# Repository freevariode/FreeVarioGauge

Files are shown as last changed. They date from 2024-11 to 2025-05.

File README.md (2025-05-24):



# FreeVario.de
</br>

### New in V2.4.2:

- files from the data folder can be uploaded OTA via the web interface
 </br>
 
### New in V2.4.1:

- Bug fix for wind display when FreeVario is only connected to Larus
 </br>
 
### New in V2.4:

- Optimization of the menu for direct connection to the Larus without OpenVario
 </br>
 
### New in V2.3:

- Improvement of device detection (XCSoar or Larus)

- improved connection to Larus

- optimized data transfer using the BT-RS232 bridge from FreeVario
 </br>
 
### New in V2.2:

- Improved wind arrow color

- STF bug fix

- in the menu, instead of using the slide switch on the board, set whether XCSoar or flap switch should switch between STF and Vario in automatic mode

- Improvements to variosound

- Improvement when setting McCready
 </br>

### New in V2.1:

- improving sound if entering update mode

- prepare VarioSound for hardware version 2.0
 </br>
 
### New in V2.0:

- Wind direction and strength of the external wind (Larus, Anemoi, etc.) is displayed

- if this is not available, the wind calculated by XCSoar is displayed

- Function can be deactivated in the menu

- the FreeVario can now also be used as a standalone device for Larus. It can be connected directly to the Larus without XCSoar 

- A FreeVario image with OpenSoar is required for OpenVario larger than 24096

- The official OpenSoar image does not yet support the feature. But that will come soon.

- With a FreeVario version lower than 1.2.2, the data folders for the sound board and the graphics board must also be re-uploaded!
 </br>
 
### New in V1.3:
 
- Bugfix: Mosquito value was not displayed correctly
</br>

### New in V 1.2.3:

- In STF mode, net Vario is now shown at the top of the display, and in Vario mode the average climb is shown. The image for the OpenVario must be larger than 23313!
</br>

### New in V 1.2.2:

- Revision of the web interface for updates

- IMPORTANT!! After the update to V 1.2.2, the two data folders must be reloaded into the memory of the display and soundboard
</br>

### New in V 1.2.1:

- the update of the two ESPs can now be carried out even more easily via the WiFi (OTA)

- IMPORTANT!! After updating to V 1.2.1, the folder data must be reloaded into the display board’s memory

- See the assembly instructions, Chapter III, variant 1, from point 17
</br>

### New in V1.2:

- Both ESPs could be updated using WiFi (OTA)
</br>

### New in V1.1.5 (OpenVario image from FreeVario.de at least 22193 required):

- Attenuation (ATT) adjustable in the menu between 0 and 3

- Altitude and speed settings, as well as damping rate and mute settings are stored in the device

- After the OpenVario crashes, the devices synchronize again

##
</br>

### IMPORTANT - PTT and mute function

If you want to use the FreeVario's mute function, you need to have at least the FreeVario image from 20295 installed on your OpenVario. In addition, at least firmware V.1.1.1 must be installed on the sound board as well as on the display board. If you are using the sound board with the 3-pin connector on the back, but without the diode D1, a small change has to be made here. Please write me about this by email (dirk@freevario.de).

The FreeVario is an open source e-variometer that works together with the XCSoar software. It shows the mean climb (30s), 
the height above sea level (MSL) or the height above ground (AGL), the ground speed (GS) or tue airspeed (TAS), the MC, 
QNH or bug value. MC, QNH, or bug value can be set via the menu and the rotary encoder, and are then passed on 
to XCSoar. In addition, a colored bar, which represents the climb value that can be grasped quickly, shows the current climb. 
The bar shows climbing green and falling red. The acoustic display of the climbing value is as known by other e-Varios and 
no longer has to be generated by the OpenVario. The OpenVario can therefore issue airspace warnings again. The volume can be 
adjusted using the lower rotary knob. The toggle switch can be used to switch between speed to fly and vario. In the middle 
position, XCSoar or a switch attached to the flaps automatically decides whether spped to fly or vario should be active.

On the back are an RJ45 and a small 2-pin socket. The e-Vario is connected to the OpenVario via the RJ45 socket. The small 
2-pin socket can be connected to a switch on the flaps.

The e-Vario fits into a 57mm standard cutout. The housing has the dimensions: 65x65x90 (LxWxD) and is printed with a 3D 
printer made of PLA or PETG

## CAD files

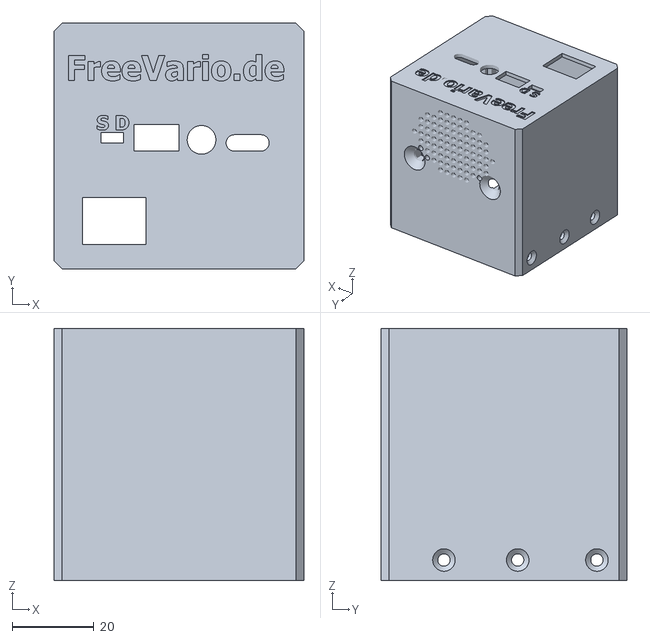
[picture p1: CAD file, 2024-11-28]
Housing/body_housing.stl
61.0 x 60.0 x 61.5

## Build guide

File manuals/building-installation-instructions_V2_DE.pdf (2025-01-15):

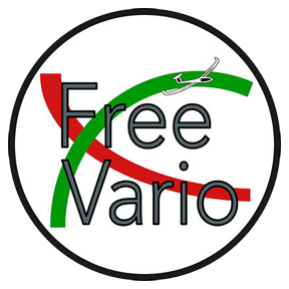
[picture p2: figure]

Copyright Dirk Jung | licensed under CC BY-SA | Page 1

## Bau- und Installationsanleitung für das FreeVario V2

## Inhaltsverzeichnis

V. Installieren des neuen OV-Images inkl. XCSoar mit FreeVario-Treiber.........13

VI. Installieren von XCSoar inkl. FreeVario-Treiber ohne Neuinstallation des OV-

XIV. Aktualisieren von Karten, Lufträumen etc. mit dem neuen Menü von

Rev. 2.2 (01.2025)

Ich arbeite auf einem Mac bzw. Linuxsystem. Auf einem Windowsrechner können Kleinigkeiten abweichen!

I. Allgemeines

Das FreeVario wird mit 12V betrieben, kann aber auch alternativ mit 5V betrieben werden.
Die Maßgenauigkeit der 3D-gedruckten Teile hängt extrem von den Einstellungen eures Druckers und vom Material ab. Es kann also vorkommen, dass die Teile zu klein sind. Dann müsst ihr die Teile um wenige Prozent größer drucken.

II. Bestücken der Platinen und Zusammenbau des e-Varios

1. PCB1 sowie auf den Bildern dargestellt zusammenlöten.

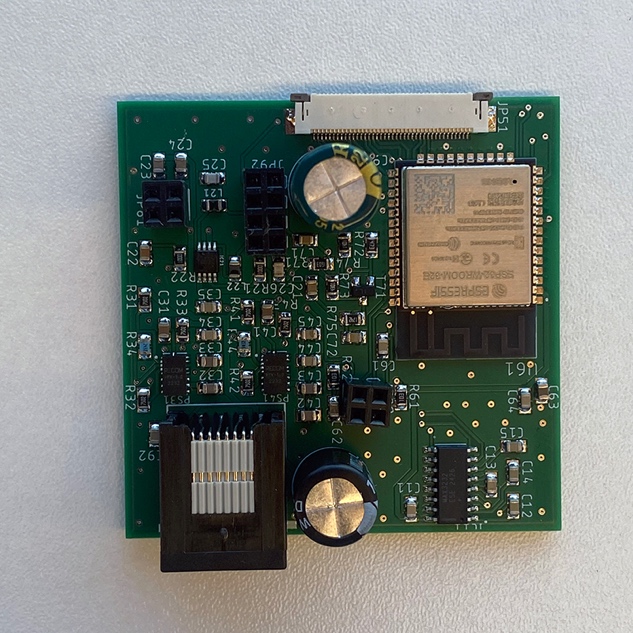
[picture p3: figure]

2. PCB2 sowie auf den Bildern dargestellt zusammenlöten. Der Abstand der beiden Kunststoffhalterungen der Stapelleiste muss auf 8mm eingestellt werden. Die zu langen Stifte mit einem Seitenschneider auf 22 mm kürzen (siehe 3. Bild).

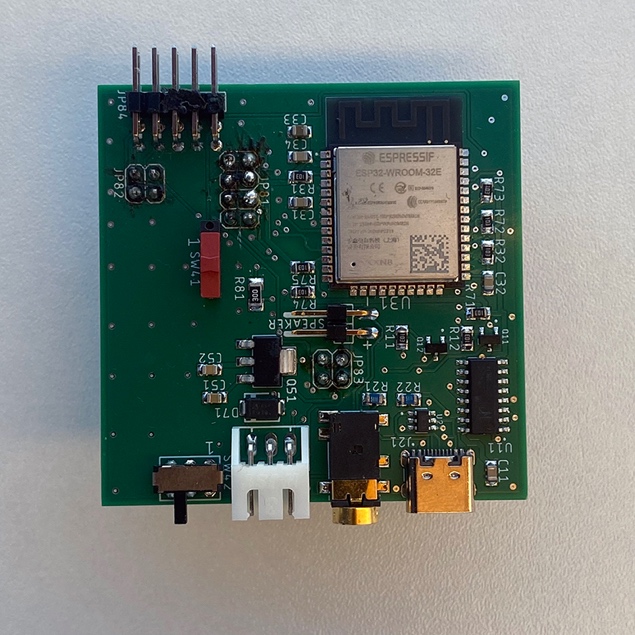
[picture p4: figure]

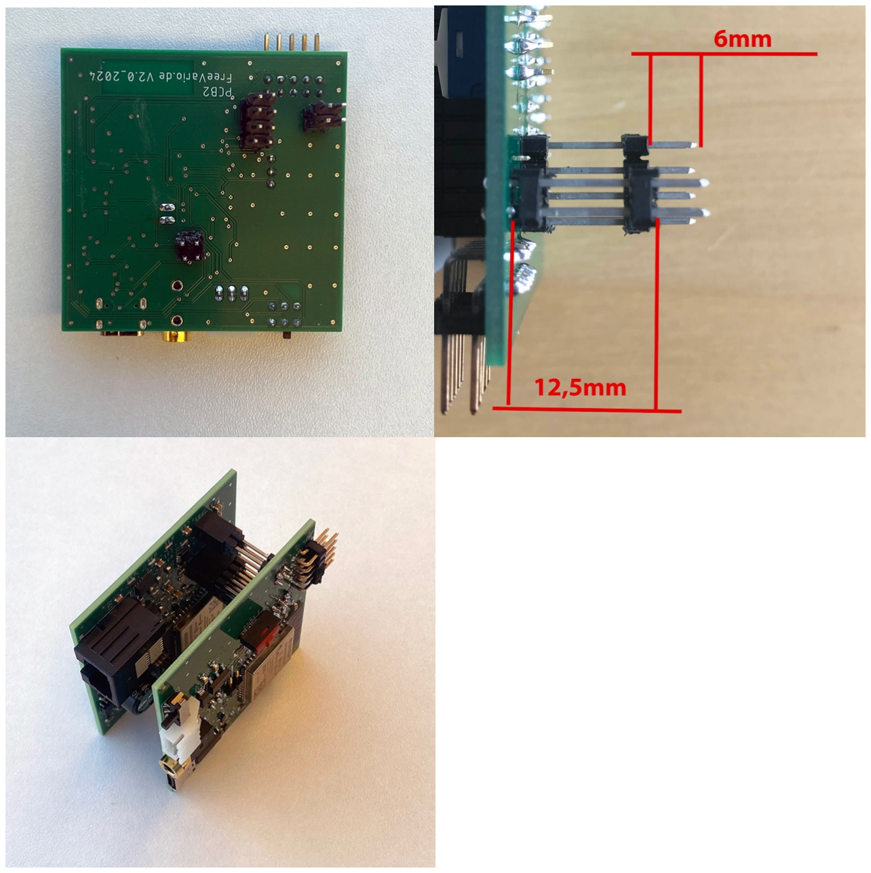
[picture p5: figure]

Die 3,5mm Klinkenbuchse dient zum Anschließen eines externen Lautsprechers. Wird der externe Lautsprecher angeschlossen, wird der interne automatisch abgeschaltet.

3. Den Drehencoder vorsichtig zerlegen, indem ihr die kleinen Metallbügel aufbiegt. Die Achse des Drehencoders ist mit einem Sicherungsring gesichert. Ihr müsst mit einem Seitenschneider vorsichtig in den Spalt zw. Achse und Gehäuseoberteil gehen und leicht drücken. Wenn die Achse durch den Seitenschneider leicht beschädigt wird, die Stelle wegfeilen. Die Achsen in die Drehmaschine einspannen auf 4mm abdrehen. Anschließend den Drehencoder wieder sorgfältig zusammensetzen und die Metallbügel zurück biegen. Die Achse des Drehencoders wieder mit dem Ring sichern. Kauft euch den Drehencoder sicherheitshalber doppelt, beim ersten Mal geht es ggf. schief. Bohrt die Hohlschrauben auf 4,3mm auf.
4. Am PCB3 an der Position, wo der Encoder sitzt, müsst ihr auf der Seite mit den 3 PINs und oben noch den überstehenden Teil der Platine wegfeilen, sonst passt die Platine nicht spannungsfrei in das Gehäuse. Es kann durchaus sein, dass ihr hier nach dem Löten noch mal ein wenig feilen müsst. Die Kontakte des Potentiometers vorsichtig um 90° nach unten biegen und anlöten. Testet, ob nach der Montage der Frontplatte die Achsen des Encoders und des Potentiometers gut durch die Hohlschrauben passen und sich leicht betätigen lassen. Gegebenenfalls noch mal lösen und etwas verschieben.

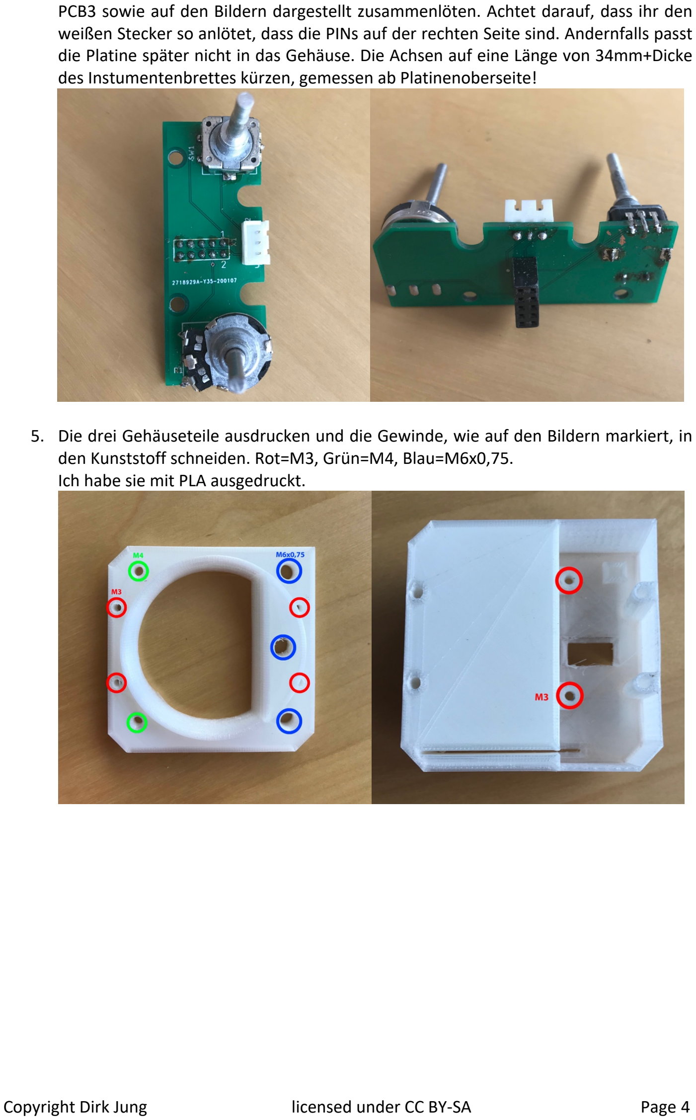
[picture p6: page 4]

PCB3 sowie auf den Bildern dargestellt zusammenlöten. Achtet darauf, dass ihr den weißen Stecker so anlötet, dass die PINs auf der rechten Seite sind. Andernfalls passt die Platine später nicht in das Gehäuse. Die Achsen auf eine Länge von 34mm+Dicke des Instumentenbrettes kürzen, gemessen ab Platinenoberseite!

5. Die drei Gehäuseteile ausdrucken und die Gewinde, wie auf den Bildern markiert, in den Kunststoff schneiden. Rot=M3, Grün=M4, Blau=M6x0,75.
Ich habe sie mit PLA ausgedruckt.

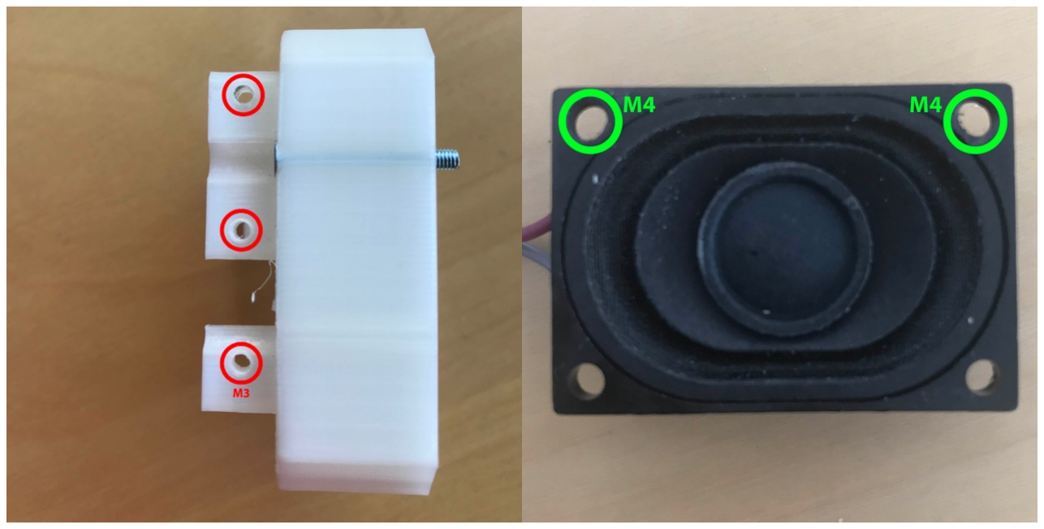
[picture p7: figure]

6. Zwei Gewinde M4 in den Lautsprecher schneiden und Lautsprecher mit 2 Senkkopfschrauben M4x8 im Gehäuse befestigen. Vorher etwa 10cm lange Kabel zum Anschließen des Lautsprechers anlöten. Der Lautsprecher ist nur erforderlich, wenn das FreeVario den Varioton ausgeben soll. Wollt Ihr weiterhin den Varioton von OpenVario nutzen, könnt ihr den Lautsprecher weglassen.
7. Stecker an ein etwa 5cm langes, 3-poliges Kabel krimpen und an den Kippschalter anlöten. Lötet so platzsparend wie möglich, in dem ihr schräg anlötet. Andernfalls gibt es später zwischen den Lötstellen und den dahinterliegenden Kontakten auf dem PCB3 einen Kurzschluss. Macht unbedingt Schrumpfschlauer die Lötkontakte!
Das mittlere Kabel kommt an die mittlere Lötfahne. Je nachdem wie ihr die beiden äußeren Kabel anlötet, habt ihr später STF oder Vario oben. Wenn ihr das obere Kabel des Steckers an die obere Lötfahne des Kippschalters, und das untere Kabel des Steckers an die untere Lötfahne des Kippschalters lötet, ist später Sollfahrt in der unteren Position des Kippschalters, und Vario in der oberen. Automatik ist in der Mitte.
8. Die Gewinde der beiden M4 Befestigungsschrauben auf 3mm + Instumentenbrettdicke kürzen. Arbeitet hier sehr genau, denn wenn die Schrauben zu lang sind, drücken Sie später auf das Display und zerstören es. Am besten ihr schraubt die Frontblende alleine einmal in das Cockpit und checkt, dass die Schrauben nicht in den Bereich des Displays ragen.
9. Kippschalter und das Display in die Frontblende einbauen.
10. PCB3 in das Mittelteil einsetzen und mit 2 Schrauben M3x6 festschrauben. Schrauben mit Gefühl anziehen, die Gewinde sind im Kunststoff!
11. Frontblende und Mittelteil mit 4 Senkkopfschrauben M3x25 zusammenschrauben. Vorher den Kippschalter anklemmen und das FFC-Kabel durch den Schlitz nach hinten führen. Schrauben mit Gefühl anziehen, die Gewinde sind im Kunststoff!

12. Testet nun zu erst, ob sich die beiden Platinen einzeln leicht in den Topf schieben lassen. Andernfalls kann es später zu Beschädigungen kommen. Im Zweifel die Nut etwas nacharbeiten.
13. PCB1 und PCB2 vorsichtig zusammensetzen, Display, Lautsprecher (Plus und Minus nicht vertauschen) und PBC3 anschließen. Den Klemmmechanismus des Displaykabels sehr vorsichtig mit einem kleinen Schraubenzieher oder ähnlichem schließen. Wenn ihr mit den Fingern oder dem falschen Werkzeug abrutscht, kann es leicht passieren, dass euch das Flachbandkabel einreißt.
14. Nun springt ihr am besten zuerst zum Programmieren der beiden ESP32, und macht anschließend hier weiter.
15. Nun den Gehäusetopf vorsichtig über die Platinen schieben. Darauf achten, dass die Platinen in den Schienen sind, und die Western-Digital-Buchse vorsichtig durch die Rückwand führen.
16. Mit 6 Senkkopfschrauben M3x6 die Gehäuseteile verschrauben. Schrauben mit Gefühl anziehen, die Gewinde sind im Kunststoff!
17. Mit den beiden Befestigungsschrauben und den beiden Hohlschrauben das Vario im I-Brett einbauen, die Drehknöpfe montieren und das Vario anschließen. Schrauben mit Gefühl anziehen, die Gewinde sind im Kunststoff!
18. Das Anschlusskabel ist auf beiden Seiten gleich belegt, d.h. gleiche Farbe auf gleichem PIN, so wie ein normales LAN-Kabel.

III. Programmieren und Updaten der beiden ESP32
Mit dem kleinen Schiebeschalter auf der Rückseite des FreeVarios könnt ihr auswählen, welchen der beiden ESP’s ihr beschreiben wollt (D=Display-ESP, S=Sound-ESP).

Variante 1: die Software-Version des FreeVarios ist kleiner als 1.2 oder die ESPs sind noch nicht programmiert worden:
1. Legt euch den Ordner Binaries z.B. auf den Desktop
2. Ladet euch ALLE Binaries von der Webseite herunter und speichert sie in diesem Ordner
3. Öffnet ein Terminal oder die Eingabeaufforderung. Dort schaut ihr, ob ihr den Pfad zu Binaries findet. Er lautet bspw. /Users/PC1/Desktop/Binaries/
4. In Arduino IDE auf Arduino -> Einstellungen klicken.
5. Unter „Zusätzliche Boardverwalter-URLs“ die URL hinzufügen. Sind schon URLs eingetragen, mit Komma und Leerzeichen weitere URLs anhängen. https://dl.espressif.com/dl/package_esp32_index.json

6. Hier außerdem unter „Ausführliche Ausgabe während“ „Hochladen“ anklicken.
7. Werkzeuge -> Board -> Boardverwalter klicken und nach ESP32 suchen.
8. „ESP32 by Espressif Systems“ auswählen und installieren.
9. Ihr müsst euch ggf. noch den Treiber für den seriellen Adapter des ESP installieren. https://sparks.gogo.co.nz/ch340.html
10. Einen neuen Sketch öffnen und speichern. Merkt euch den Namen. Zum Hochladen folgendes unter Werkzeuge einstellen:
- Board: DOIT ESP32 DEVKIT V1
- Upload Speed: 115200
- Flash Frequency: 80MHz
- Core Debug Level: “Keine”
- Port: Schaue, welche nach dem Anschließen des ESP32 mit dem USB-Kabel neu dazu kommt
11. Dann den leeren Sketch hochladen. Über der Fehlermeldung im Arduino IDE steht in weißer Schrift ein sehr langer Befehl, der in etwa wie folgt lautet: /Users/PC1/Documents/Arduino/hardware/espressif/esp32/tools/esptool/esptool --chip esp32 --port /dev/cu.SLAB_USBtoUART --baud 115200 --before default_reset --after hard_reset write_flash -z --flash_mode dio --flash_freq 80m --flash_size detect 0xe000
/Users/PC1/Documents/Arduino/hardware/espressif/esp32/tools/partitions/boot_ap p0.bin 0x1000
/Users/PC1/Documents/Arduino/hardware/espressif/esp32/tools/sdk/bin/bootloader _dio_80m.bin 0x10000
/var/folders/6t/qjgfw2413f7ddnjzk_08btxw0000gp/T/arduino_build_661147/sketch_ dec30d.ino.bin 0x8000
/var/folders/6t/qjgfw2413f7ddnjzk_08btxw0000gp/T/arduino_build_661147/sketch_ dec30d.ino.partitions.bin
12. Diesen Befehl kopieren, den braucht ihr um die Datei auf den ESP32 zu laden.
13. Der erste Teil des Befehls zeigt euch, wo Arduino IDE sein Arbeitsverzeichnis anlegt. Merkt euch den Ort. In diesem Beispiel wäre das: /Users/PC1/Documents/Arduino
14. Ändert den Befehl mit eurem Ort, an dem der Ordner Binaries liegt, ab. Ändert außerdem die beiden letzten Dateinamen wie folgt ab (siehe Fettdruck).

Display-ESP:
/Users/PC1/Documents/Arduino/hardware/espressif/esp32/tools/esptool/esptool --chip esp32 --port /dev/cu.SLAB_USBtoUART --baud 115200 --before default_reset --after hard_reset write_flash -z --flash_mode dio --flash_freq 80m --flash_size detect 0xe000 /Users/PC1/Desktop/Binaries/boot_app0.bin 0x1000 /Users/PC1/Desktop/Binaries/FreeVarioGauge.ino.bootloader.bin 0x10000

/Users/PC1/Desktop/Binaries/FreeVarioGauge.ino.bin 0x8000 /Users/PC1/Desktop/Binaries/FreeVarioGauge.ino.partitions.bin
Sound-ESP:
/Users/PC1/Documents/Arduino/hardware/espressif/esp32/tools/esptool/esptool --chip esp32 --port /dev/cu.SLAB_USBtoUART --baud 115200 --before default_reset --after hard_reset write_flash -z --flash_mode dio --flash_freq 80m --flash_size detect 0xe000 /Users/PC1/Desktop/Binaries/boot_app0.bin 0x1000 /Users/PC1/Desktop/Binaries/VarioSound.ino.bootloader.bin 0x10000 /Users/PC1/Desktop/Binaries/VarioSound.ino.bin 0x8000 /Users/PC1/Desktop/Binaries/VarioSound.ino.partitions.bin
15. Den ESP32 mit dem USB-Kabel am PC anschließen und ein Terminal bzw. die Eingabeaufforderung öffnen. Dort den jeweils passenden Befehl absetzen.
16. Nachdem der Upload abgeschlossen ist, startet der ESP32 neu. Anschießend müssen noch die Dateien in den Speicher des jeweiligen ESP32 hochgeladen werden.
17. Das Programm ESP32 Sketch Data Upload funktioniert aktuell nur bis Ardoino IDE 1.8.19!
18. ESP32 | Sketch | Data | Upload | installieren. | Dazu | ESP32FS-1.1.zip | bei
https://github.com/me-no-dev/arduino-esp32fs-plugin/releases/ herunterladen.
19. Auf dem Mac den entpackten Ordner ESP32FS nach /Dokumente/Arduino/tools kopieren.
20. Unter Windows den entpackten Ordner ESP32FS nach /Programme/Arduino/tools kopieren.
21. Die Dateien sound_data.zip und display_data.zip von der Webseite herunterladen und entpacken. Geht in das Arbeitsverzeichnis von Arduino IDE (z.B. /Users/PC1/Documents/Arduino) und dort in den Ordner eures eben angelegten Sketches. Hierher den entpackten Ordner data für den Sound-ESP oder den Display ESP kopieren, je nach dem auf welchen ihr gerade hochladen wollt.
22. Arduino IDE neu starten, euren neu angelegten Sketch öffnen.
23. WICHTIG!! Darauf achten, dass der serielle Monitor geschlossen ist.
24. Nun unter Werkzeuge „ESP32 Sketch Data Upload“ anklicken.
25. Nach dem der Upload abgeschlossen ist, startet der ESP32 neu und, falls das Display schon angeschlossen ist, seht ihr nun auch die Anzeige des e-Varios.
26. Nun geht zurück zu Punkt 13 des Montageteils der Anleitung.

Variante 2: die Software-Version des FreeVarios ist 1.2:

Anmelden der ESPs in einem WLAN
1. Schaltet das FreeVario ein und lasst, wenn möglich, das OpenVario aus. Sollte es nicht möglich sein, die Geräte unabhängig voneinander einzuschalten, beendet über das Menü im OpenVario XCSoar. Während des Updates sollte XCSoar nicht versuchen mit dem FreeVario zu kommunizieren.
2. Solange das Display die Versionsnummer zeigt, könnt ihr in den Update-Modus wechseln.
3. Legt dazu den Kippschalter von der obersten in die unterste, oder von der untersten in die oberste Position.
4. Das Soundboard quittiert den Update-Modus mit einem Peepston, das Displayboard zeigt auf dem Bildschirm „starting Update Mode“ an.
5. Finden die beiden ESPs kein WLAN, mit dem sie sich verbinden können, starten Sie im Access Point Mode, das bedeutet, sie stellen selbst ein WLAN zur Verfügung.
6. Da eine Weile versucht wird, sich in ein WLAN einzuwählen, kann dieser Prozess etwa 1 Minute dauern.
7. In welchem Modus sich welcher ESP befindet, und über welche IP er erreichbar ist, wird auf dem Bildschirm angezeigt.
8. Der Access Point des Soundboards heißt „FreeVario_Soundboard“, der Access Point des Displayboard heißt „FreeVario_Displayboard”
9. Verbindet euch mit eurem Rechner oder Handy mit einem der beiden Access Points und ruft im Browser die jeweils angezeigte IP auf.
10. Dort findet ihr eine Liste der gefundenen WLAN-Netzwerke. Sucht euch das aus, mit dem sich der ESP verbinden soll, und gebt die passende SSID und das WLAN-Passwort ein.
11. Nun werden die Verbindungsdaten im EEPROM gespeichert. Dort können nur die Verbindungsdaten für ein WLAN gespeichert werden. Wenn ihr euch mit einem anderen verbindet, werden die alten Verbindungsdaten gelöscht.
12. Startet das FreeVario neu, geht wieder in den Update-Mode und wiederholt die Schritte 9 – 11 mit dem anderen Access Point.
13. Die Schritte 1 – 12 müsst ihr zukünftig nicht wiederholen, wenn ihr im gleichen WLAN bleibt.

ESPs verbinden sich bereits mit einem WLAN
14. Ladet euch von FreeVario.de die Binarie-Dateien VarioSound.ino.bin und FreeVarioGauge.ino.bin herunter und speichert sie auf eurem Gerät.
15. Startet das FreeVario wieder neu und geht wieder in den Update-Mode.
16. Nun verbinden sich beide ESPs mit dem ausgewählten WLAN. Verbindet euren Rechner oder euer Handy ebenfalls mit diesem WLAN und ruft im Browser einer der beiden im Display angezeigten IPs auf.
17. Tragt beim Soundboard jeweils für Passwort und Login „Sound“ ein.
18. Tragt beim Displayboard jeweils für Passwort und Login „Display“ ein.
19. Wählt beim Soundboard die Datei VarioSound.ino.bin, und beim Displayboard die Datei FreeVarioGauge.ino.bin aus und klickt auf Update.
20. Das Update dauert ca. 1 Minute und die erfolgreiche Beendigung wird beim Displayboard durch einen Neustart des Displays angezeigt. Beim Soundboard erhält man leider keine Rückmeldung.
21. Startet das FreeVario neu, geht wieder in den Update-Mode und wiederholt die Schritte 16 – 20 für den anderen ESP.
22. Nach einem erneuten Neustart des FreeVarios ist der Vorgang abgeschlossen.

Variante 3: die Software-Version des FreeVarios ist mindestens 1.2.1:
1. Ladet euch von FreeVario.de die Binarie-Dateien VarioSound.ino.bin und FreeVarioGauge.ino.bin herunter und speichert sie auf eurem Gerät.
2. Schaltet das FreeVario ein und lasst, wenn möglich, das OpenVario aus. Sollte es nicht möglich sein, die Geräte unabhängig voneinander einzuschalten, beendet über das Menü im OpenVario XCSoar. Während des Updates sollte XCSoar nicht versuchen mit dem FreeVario zu kommunizieren.
3. Solange das Display die Versionsnummer zeigt, könnt ihr in den Update-Modus wechseln.
4. Legt dazu den Kippschalter von der obersten in die unterste, oder von der untersten in die oberste Position.
5. Das Soundboard quittiert den Update-Modus mit einem Peepston, das Displayboard zeigt auf dem Bildschirm „starting Update Mode“ an.
6. Nun stellt das Displayboard das WLAN FV_Displayboard, und das Soundboard das WLAN FV_Soundboard zur Verfügung. Das Passwort ist jeweils 12345678.
7. Das WLAN des ESP32 erzeugt Störgeräusche im Audioverstärker, das ist leider normal.

8. Wenn ihr euch mit einem der beiden WLAN’s verbunden habt, könnt ihr die Updateseite des jeweiligen Boards in eurem Browser aufrufen.
9. Gebt dazu als URL FreeVario_Displayboard.local bzw. FreeVario_Soundboard.local, oder alternativ die auf dem Display angezeigte IP ein.
10. Wählt beim Soundboard die Datei VarioSound.ino.bin, und beim Displayboard die Datei FreeVarioGauge.ino.bin aus und klickt auf Update.
11. Das Update dauert ca. 1 Minute und die erfolgreiche Beendigung wird beim Displayboard durch einen Neustart des Displays angezeigt. Beim Soundboard erhält man leider keine Rückmeldung.
12. Startet das FreeVario neu, geht wieder in den Update-Mode und wiederholt die Schritte 16 – 20 für den anderen ESP.
13. Nach einem erneuten Neustart des FreeVarios ist der Vorgang abgeschlossen.

IV. Sichern und wiederherstellen eurer Einstellungen

1. Sichern der Einstellungen:

Variante 1: das originale Menü wird verwendet:
- Sichern des Ordners .xcsoar vom alten System
- OpenVario booten und ins Menü gehen. Dort „Exit to the shell“ auswählen und mit Yes bestätigen. Euren USB-Stick zum Verwalten des OpenVarios und eine USB-Tastatur anschließen. Gebt folgende Befehle ein.
- mkdir /tmp/USB
- mount /dev/„USB-Stick“ /tmp/USB (/„USB-Stick“ ist i.d.R. /dev/sda1)
- cp -r .xcsoar /tmp/USB (dauert etwas!)
- cd /tmp/USB
- mv .xcsoar xcsoar
- rm -r openvario/upload/xcsoar
- mv xcsoar openvario/upload/
- Sichern des Wertes zur Kalibrierung der Spannungsanzeige (falls ihr das überhaupt kalibriert habt, ansonsten Schritt überspringen):
- OpenVario booten und ins Menü gehen. Dort „Exit to the shell“ auswählen und mit Yes bestätigen. Schließt eine USB-Tastatur an und gebt folgende Befehle ein.
- nano /opt/conf/sensord.conf
- den Wert bei der Variablen „voltage_config” aufschreiben. Bei mir war das „voltage_config 1592.4 4.54545“.
- 1592.4 ist der Skalierungsfaktor, 4.54545 ist der Offset. Die Formel, um den Wert des AD-Wandlers in die Spannung umzurechnen, lautet:
U = (Wert AD-Wandler / Skalierungsfaktor) + Offset

- Sichern der WiFi-Einstellungen:
- Kopiert euch den Ordner /var/lib/connman auf den USB-Stick, der ja bereits gemountet ist.
- cp -r /var/lib/connman /tmp/USB

Variante 2: das neue Menü von Kedder wird verwendet:
- Steckt einen leeren FAT32 formatierten USB-Stick in das OpenVario
- Startet das OpenVario und wählt im Menü „Applications“ -> „Backup“ -> „Backup“ aus
- Alles wichtige wird nun automatisch gesichert
2. Hochladen eurer gesicherten Daten auf das OpenVario:

Variante 1: das originale Menü wird verwendet:
- Die neue SD-Karte in das OpenVario einsetzen, und starten. Dann wieder in das Menü von OpenVario gehen.
- „Copy file to and from OpenVario” -> „Upload files from USB to XCSoar” anklicken. Damit werden alle eure Einstellungen wiederhergestellt. Warten bis „Done!!“ Angezeigt wird.
- Anschließend unter „Update, Settings, …” -> „System Settings” mit „Set rotation of the display” die gewünschte Ausrichtung des Displays einstellen.
- Ggf. unter „Update, Settings, …” „Calibrate Touch” auswählen.
- unter „Update, Settings, …” „Calibrate Sensors” auswählen.
- Zuletzt noch unter „Update, Settings, …” -> „System Settings” -> „Set language used for XCSoar” die Sprache einstellen.
- Mit ESC zurück ins Hauptmenü und „Restart“ auswählen und mit Yes bestätigen.
- Kalibrierung der Spannungsanzeige wiederherstellen:
- nano /opt/conf/sensord.conf
- „voltage_config” wieder auf die notierten Werte setzen
- Sicherung alter WiFi-Einstellungen wiederherstellen:
- Den auf dem USB-Stick gesicherten Ordner connman wieder in das Verzeichnis /var/lib kopieren
- mkdir /tmp/USB
- mount /dev/„USB-Stick“ /tmp/USB (/„USB-Stick“ ist i.d.R. /dev/sda1)
- cp -r /tmp/USB/connman /var/lib
- WiFi wieder einrichten, wenn keine Sicherung der alten Einstellungen besteht:
- OpenVario booten und ins Menü gehen. Dort „Exit to the shell“ auswählen und mit Yes bestätigen. Schließt eine USB-Tastatur an und gebt folgende Befehle ein.
- connmanctl
- enable wifi
- scan wifi
- services
- agent on
- connect wifi_...
- Passwort eingeben

Variante 2: das neue Menü von Kedder wird verwendet:
- Steckt den USB-Stick mit eurer Sicherung in das OpenVario
- Startet das OpenVario und wählt im Menü „Applications“ -> „Backup“ -> „Restore“ aus
- Alles wichtige wird nun automatisch wieder hergestellt
V. Installieren des neuen OV-Images inkl. XCSoar mit FreeVario-Treiber
1. Ab dem offiziellen Image 21033 von OpenVario ist der FreeVario-Treiber im Image integriert. Ihr seid also nicht mehr darauf angewiesen, Images von FreeVario.de zu verwenden. Solltet ihr bereits ein Image ab 21033 installiert haben, könnt ihr das FreeVario direkt ohne Änderungen an eurer Software anschließen.
2. Installieren des neuen Images:

Variante 1: Neue SD-Karte verwenden (sichere Methode)
- Mit einem Linux-PC das neue Image auf eine andere SD-Karte schreiben. So könnt Ihr sicher sein, dass auf der alten Karte noch ein funktionierendes System ist, falls etwas schief geht.
- das Image zuerst entpacken:
- gunzip “Pfad_zum_Image“
- z.B.: gunzip /home/USER/Schreibtisch/OpenVario-linux-openvario-image-testing-glibc-ipk-20149-openvario-7-PQ070.rootfs.img.gz
- dd if=“Pfad_zum_Image“ of=/dev/„neue_SD-Karte“
- z.B.: dd if=OpenVario_neu.img of=/dev/sda

Variante 2: Alte SD-Karte überschreiben (unsichere Methode)
- In das Hauptverzeichnis des USB-Sticks „openvario“ legt ihr die recovery-Datei „ov-recovery.itb“, die ihr auf dem FTP-Server (ftp://ftp.openvario.org/recovery) herunterladen könnt.
- WICHTIG!! Wenn ihr keine Wiederherstellung durchführen wollt, muss die Datei „ov-recovery.itb“ unbedingt umbenannt werden, z.B. in „ov-recovery.xxx“.
- Kopiert das zu installierende Image als .gz-Datei auf den USB-Stick in den Unterordner images
- Steckt den USB-Stick in das OpenVario und bootet.
- Das Wiederherstellungsmenü wird in Rot dargestellt. Denkt daran, dass beim Ausführen der Wiederherstellung alle Dateien im OpenVario gelöscht werden!
- Wählt „Write image to SD Card“ und anschließend „Update complete SD Card“ aus

VI. Installieren von XCSoar inkl. FreeVario-Treiber ohne Neuinstallation des OV-Images

1. Wenn ihr nicht dass komplette Image von OV neu installieren wollt, sondern nur die Version von XCSoar austauschen wollt, dann könnt ihr das wie unten beschrieben tun. Dabei bleiben eure Einstellungen in XCSoar komplett erhalten. Eine Sicherungsdatei der SD-Karte würde ich mir aber immer vorher anlegen. Schief gehen kann immer mal was!
2. Die neue Version der Installationsdatei von XCSoar auf einen USB-Stick kopieren, im Menü von OpenVario „Exit to the shell“ auswählen. Dort mit fdisk -l den Pfad des USB-Stick finden (z.B. /dev/sda1).
3. mkdir /tmp/USB
4. mount /dev/sda1 /tmp/USB
5. cd /tmp/USB
6. opkg remove xcsoar
7. opkg install xcsoar*.ipk
8. Im Menü von OpenVario noch mal die Sprache neu einstellen, und einen Reboot machen.

VII. Abschalten des Variotons vom OpenVario

### 1. Überspringt diesen Abschnitt komplett, wenn ihr den Varioton von OpenVario

weiter nutzen wollt. Wollte ihr das FreeVario den Ton ausgeben lassen, müsst ihr diesen Abschnitt durcharbeiten.

2. Geht über das OpenVario Menü auf „Exit to the shell“ und gebt dort den Befehl „systemctl disable variod“ ein, um den Varioton von OpenVario abzuschalten.
3. Das OpenVario neu starten.
4. Ändert den Port des NMEA-Anschlusses A von 4352 auf 4353.
5. Sollte weiterhin in XCSoar ein Varioton zu hören sein, wird dieser vom XCSoar erzeugt.
6. Unter System -> Anzeige -> Audio-Vario Audio-Vario auf Ein und die Lautstärke auf 0% stellen. Mit Schließen bestätigen.

VIII. Einstellungen Doppelsitzer

1. Um das vordere und hintere OpenVario miteinander zu verbinden, müsst ihr ein gekreuztes Kabel verwenden. Das heißt, ihr müsst die PINs 5 un6 für RX und TX an einem Stecker vertauschen.

2. Das vordere Gerät wird auf die zu verwendende RJ45-Buchse eingestellt, z.B. ttyS3, als Treiber wird NMEA output eingestellt, die Baudrate z.B. auf 38400 (sie muss vorne und hinten gleich sein!
3. Das hintere Gerät wird ebenfalls auf die zu verwendende RJ45-Buchse eingestellt, z.B. ttyS3, als Treiber wird OpenVario eingestellt, und die Baudrate ist gleich mit dem vorderen Gerät einzustellen.

IX. Sperren des Standardprofils für den Vereinseinsatz

1. Geht im Hauptmenü des OpenVario in die Konsole, in dem ihr „Exit to Shell“ auswählt.
2. Geht mit „cd .xcsoar“ in das Verzeichnis, in dem die Profile abgelegt werden.
3. Standardmäßig heißt das Profil openvario.prf. Ich habe es in clubprofile.prf umbenannt (mv openvario.prf clubprofile.prf)
4. Mit folgendem Befehl das Profil sperren:
chattr +i clubprofile.prf
5. Mit folgendem Befehl das Profil entsperren: chattr -i clubprofile.prf
X. Einstellungen in XCSoar
1. Unter Konfig. -> NMEA-Anschluss einen freien Anschluss aus A, B, C oder D auswählen und auf Bearbeiten klicken.
2. Du Zuordnung der Anschlüsse sollte so gewählt werden, dass das Flarm über dem FreeVario steht.
3. Bei Anschluss wählt ihr den Anschluss, an dem das e-Vario angeschlossen wurde (z.B. ttyS1).
4. Baudrate ist 115200, Treiber ist FreeVario, mit OK und Schließen bestätigen.

XI. Einstellungen für die Knüppelfernbedienung mit FreeVario

Um den STF-Schalter zum Steuern des FreeVarios im Automatikmodus nutzen zu können, müssen ein paar Einstellungen gemacht werden. Anschließend funktioniert die Umstellung von Vario zu STF, oder umgekehrt, wie folgt:

1. Priorität hat der Kippschalter des FreeVarios. Wird mit ihm STF oder Vario gewählt, wird das FreeVario auf den jeweiligen Modus gestellt. Steht der Kippschalter des FreeVarios auf Automatik, kommt die 2. Priorität zum Tragen.
2. Priorität hat die Knüppelfernbedienung. Ein kurzer Klick aktiviert Vario, ein langer Klick STF und ein Doppelklick den Automatikmodus. Der mit der Knüppelfernbedienung eingestellte Modus wird an das FreeVario und an das OpenVario zum Ändern des Tons geschickt. Ist auch die Knüppelfernbedienung im Automatikmodus, ist die dritte Priorität aktiv.
3. Priorität hat, je nach dem welche Option im Menü unter STF gewählt wurde, jetzt XCSoar oder ein an den Wölbklappen angeschlossener Schalter. Auch hier wird im Moment nur das FreeVario umgeschaltet. Ein Befehl an das OpenVario zum Umschalten des Tons geht im Moment nicht.

Wichtig!! Stellt in XCSoar auf Device A OpenVario und auf Device B FreeVario ein. Ansonsten funktioniert es nicht!!

1. Auf dem OpenVario muss das Image der FreeVario-Seite neuer als 22028 installiert sein. Wie das geht, steht im Kapitel V.
2. Auf dem FreeVario müssen die ESPs des Display- und des Soundboards mindestens auf die Version 1.1.4 upgedated werden. Wie das geht, steht in Kapitel III.
3. Wenn ihr die Datei openvario.xci original aus dem Image verwendet, und nicht zum Sortieren des Menüs oder ähnliches verändert habt, braucht ihr hier nicht zu tun. Vorsicht, wenn ihr ein Backup einspielt, wird die Datei openvario.xci automatisch mit eurer alten Version überschrieben. Dann solltet ihr vorher die Datei in eurem Backup mit einem Texteditor ändern. Der Texteditor darf keine Textformatierung durchführen, ich verwende dafür VSCode. Wenn ihr eine eigene Datei verwendet, müsst ihr die folgenden Änderungen ebenfalls durchführen:

mode=default
type=key
data=V
event=SendNMEAPort1 POV,C,VAR event=StatusMessage Vario Mode

mode=default
type=key
data=S
event=SendNMEAPort1 POV,C,STF event=StatusMessage Speed to Fly Mode

ändern zu:

mode=default
type=key
data=V
#event=SendNMEAPort1 POV,C,VAR

event=SendNMEAPort2 PFV,REM,C #event=StatusMessage Vario Mode

mode=default
type=key
data=S
#event=SendNMEAPort1 POV,C,STF event=SendNMEAPort2 PFV,REM,S #event=StatusMessage Speed to Fly Mode

mode=default
type=key
data=A
event=SendNMEAPort2 PFV,REM,A #event=StatusMessage Automatic Mode
4. Benutz ihr eine Variante der Knüppelfernbedienung mit Kippschalter, könnt ihr die restlichen Menüpunkte überspringen. Habt ihr eine Version mit Taster, müsst ihr eure Knüppelfernbedienung aktualisieren.
5. Wie das geht, hat Stefan Langer hier in einem Video veröffentlicht: https://youtu.be/vwJqPAwFBlU
6. Dazu installiert ihr auf eurem PC Arduino IDE (https://www.arduino.cc/en/software)
7. Dann ladet ihr euch in unserem Downloadbereich die Datei bounce.zip herunter, entpackt sie und legt den entpackten Ordner im library-Verzeichnis von Arduino IDE ab. Wo ihr das library-Verzeichnis findet, hängt von dem Betriebssystem auf eurem Computer ab. Googled es am besten.
8. Dann ladet ihr euch bei uns die Datei Stick_Remote_Control_FV.zip herunter und entpackt sie
9. Öffnet die Datei Stick_Remote_Control_FV.ino
10. Klickt in der Arduino IDE auf Werkzeuge und wählt bei Board das Arduino Leonardo aus
11. Als Port wählt ihr den, der als letztes dazu kam, als ihr die Knüppelfernbedienung mit dem Computer über das USB-Kabel verbunden habt
12. Klickt auf „Upload“ und das war es auch schon

XII. Einstellungen für die Knüppelfernbedienung ohne FreeVario

Wenn ihr ein Backup eurer OpenVario-Einstellungen einspielt, wird die Datei openvario.xci automatisch mit eurer alten Version überschrieben, und sollte wieder korrekt eingestellt sein. Verwendet ihr stattdessen die originale Datei openvario.xci aus dem Image, müsst ihr ein paar Anpassungen durchführen. Um die Änderungen in der Datei openvario.xci durchzuführen, müsst ihr einen Texteditor, der keine Textformatierung durchführt, verwenden. Ich verwende dafür VSCode. Folgende Änderungen müssen durchgeführt werden:

mode=default
type=key
data=V
#event=SendNMEAPort1 POV,C,VAR event=SendNMEAPort2 PFV,REM,C #event=StatusMessage Vario Mode

mode=default
type=key
data=S
#event=SendNMEAPort1 POV,C,STF event=SendNMEAPort2 PFV,REM,S #event=StatusMessage Speed to Fly Mode

ändern zu:

mode=default
type=key
data=V
event=SendNMEAPort1 POV,C,VAR #event=SendNMEAPort2 PFV,REM,C event=StatusMessage Vario Mode

mode=default
type=key
data=S
event=SendNMEAPort1 POV,C,STF #event=SendNMEAPort2 PFV,REM,S event=StatusMessage Speed to Fly Mode

XIII. Installation des neuen OpenVario Menüs von Kedder

1. Das OpenVario muss mit dem Internet verbunden und es muss einen Tastatur angeschlossen sein.
2. Startet OpenVario und geht in das OV-Menü. Dort „Exit to the shell“ auswählen und mit Yes bestätigen.

3. Gebt dort folgenden Befehl ein: - | wget https://raw.githubusercontent.com/kedder/openvario-shell/master/scripts/openvario-shell-install.sh -
| O - | sh
4. Mit ESC zurück ins Hauptmenü und „Restart“ auswählen und mit Yes bestätigen. Das
neue Menü wird ab jetzt verwendet.
5. Soll das Menü wieder deinstalliert werden, verwendet den Befehl:
- wget https://raw.githubusercontent.com/kedder/openvario-shell/master/scripts/openvario-shell-uninstall.sh -O - | sh
6. Ein Update des Menüs kann über das Menü selber, oder in der Konsole durchgeführt werden. In der Konsole sind folgende Befehle notwendig: - opkg update
- opkg upgrade

XIV. Aktualisieren von Karten, Lufträumen etc. mit dem neuen Menü von Kedder

1. Legt euch wie zuvor im Kapiten IV Variante 2 beschrieben einen USB-Stick mit eurem Backup an
2. Steckt den Stick in euren PC und geht in das Verzeichnis /openvario/backup/home/root/.xcsoar
3. Legt die Dateien, die ihr aktualisieren möchtet, hier ab
4. Steckt den Stick in das OpenVario
5. Startet das OpenVario und wählt im Menü „Applications“ -> „Backup“ -> „Restore“ aus
6. Alle Dateien, die neuer sind als die auf dem OpenVario, werden aktualisiert

XV. Verwenden eines LTE-Sticks

1. Wird auf dem OpenVario ein Image größer 22163 von Freevario verwendet, kann es mit einem LTE-Stick (Huawei E3372h-320) online gehen
2. Bei der SIM-Karte muss die PIN-Abfrage ausgeschaltet werden
3. Den Stick einfach in einen freien USB-Port stecken und wenn er mit dem Mobilfunknetz verbunden ist, könnt ihr über LTE online gehen und bspw. Wetterinformationen von PCMet herunterladen

XVI. Einbau
1. USB-C-Anschluss zum Updaten der beiden ESP‘s
2. 3,5mm Klinkenbuchse für externen Lautsprecher
3. Stecker für Sollfahrtschalter/Wölbklappenschalter und PTT-Taste
a. PTT
b. Sollfahrt-Schalter
c. Sollfahrt-Schalter
4. Schalter, welcher ESP ein Update erhalten soll
5. IGC-Stecker für OpenVario

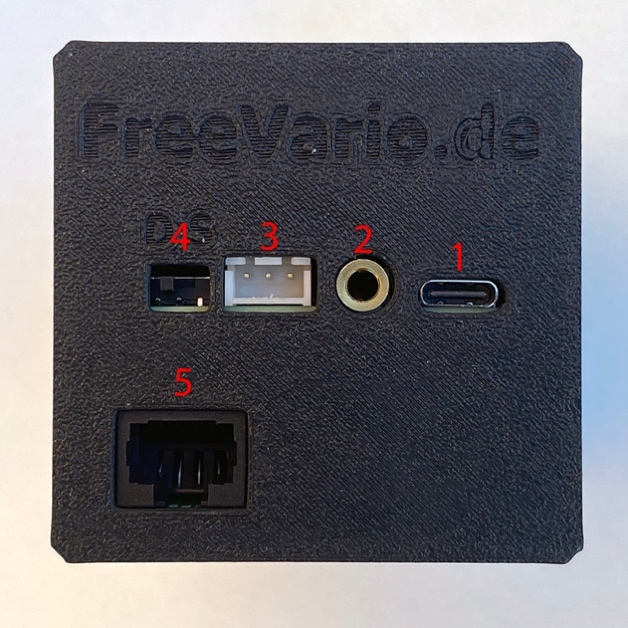
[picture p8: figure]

1. Die beiden Hohlschrauben über die Achse des Encoders bzw. Potentiometers schieben und mit dem FreeVario verschrauben
2. Die beiden M4 Schrauben unbedingt vor der Montage kürzen (3mm + Instumentenbrettdicke) und auf richtige Länge prüfen, da ansonsten das Display zerstört wird!
3. Das FreeVario mit den Schrauben M4 befestigen
4. Die beiden Drehknöpfe festschrauben. Darauf achten, dass der Encoderknopf genug Platz nach hinten hat, damit der Pushbutton funktioniert
5. Abdeckkappen auf Drehknöpfe anbringen
6. FreeVario an OpenVario mit einem IGC-konformen Kabel anschließen. Wird das FreeVario an OpenVario angeschlossen, verwendet ein 1:1 Kabel. Wird es an Larus angeschlossen, muss ein gekreuztes Kabel verwendet werden.
7. An dem drei-poligen Stecker ggf. Wölbklappenschalter (geschlossen, wenn auf STF gestellt werden soll) und PTT-Taste anschließen
8. Um Empfangsprobleme zu vermeiden, sollten die Antennen anderer Geräte möglichst weit vom FreeVario entfernt montiert werden

Until hardware version V2.0
1. Audio +
2. NC
3. Audio -

from hardware version V2.1
1. Audio +
2. Audio -
3. GND

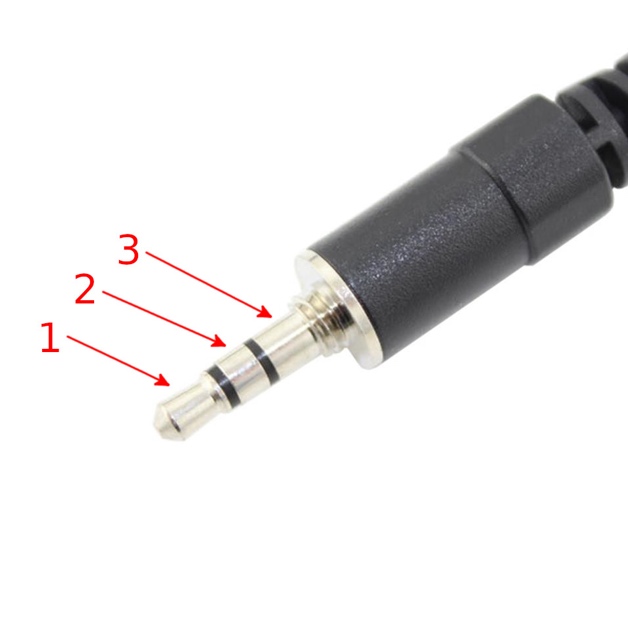
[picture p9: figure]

XVII.Ausschlusserklärung

Das e-Vario ist nicht EASA- oder FAA-zertifiziert. Dies gilt im Übrigen für viele kommerzielle e-Varios und Flugcomputer, die ihr wahrscheinlich gewohnt seid.

Wenn ihr wissen möchtet, ob ihr dieses e-Vario in eurem Segelflugzeug legal verwenden dürft, wendet euch an euren Prüfer. Könnt ihr legal einen anderen (auch nicht zertifizierten) Flugcomputer anderer Hersteller installieren? Wenn ja, solltet ihr auch dieses e-Vario legal installieren dürfen. Wenn euer Flugzeug unter die EASA-Regeln fällt, lest CS-STAN, Standardänderung CS-SC402a.

Es handelt sich bei diesem Instrument um ein Bastelprojekt und nicht um ein luftfahrtzugelassenes Instrument. Ich weise ausdrücklich darauf hin, dass der Einsatz unter Ausschluss jeglicher Gewährleistung auf eigenes Risiko erfolgt!

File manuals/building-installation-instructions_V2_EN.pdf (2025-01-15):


Copyright Dirk Jung | licensed under CC BY-SA | Page 1

## Construction and installation instructions for the FreeVario V2

## Table of Contents

VI. Install XCSoar incl. FreeVario driver without reinstalling the OV

XIV. Update maps, airspaces etc. with the new menu from

Rev. 2.2 (01.2025)

I work on a Mac or Linux system. Little things can differ on a Windows computer!

I. General

The FreeVario is operated with 12V, but can also alternatively be operated with 5V. The dimensional accuracy of the 3D printed parts is extremely dependent on the settings of your printer and the material. So it can happen that the parts are too small. Then you have to print the parts a few percent larger.

II. Assembling the boards and assembling the vario gauge

1. Solder PCB1 as well as shown in the pictures.


2. Solder PCB2 together as shown in the pictures. The distance between the two plastic brackets of the stacking bar must be set to 8mm. Shorten the pins that are too long to 22 mm (see 3rd picture).



The 3.5mm jack socket is used to connect an external speaker. If the external speaker is connected, the internal one is automatically switched off.

3. Carefully disassemble the rotary encoder by bending the small metal brackets. The axis of the rotary encoder is secured with a locking ring. You have to go carefully with a side cutter into the gap between the axis and the upper part of the housing and press lightly. If the axis is slightly damaged by the side cutter, file away the spot. Clamp the axes in the lathe, turn by 4mm. Then carefully reassemble the rotary encoder and bend the metal brackets back. Secure the axis of the rotary encoder again with the ring. For safety's sake, buy the encoder twice, the first time it may go wrong. Drills the banjo bolts to 4.3mm.
4. On the PCB3 at the position where the encoder is located, you have to file away the protruding part of the board on the side with the 3 PINs and above, otherwise the board will not fit into the housing without tension. It may well be that you have to file a little more after soldering. Carefully bend the contacts of the potentiometer downwards by 90° and solder them on. Tests whether the axes of the encoder and the potentiometer fit well through the banjo bolts and are easy to operate after installing the front plate. If necessary, loosen again and move something.Solder PCB3 as well as

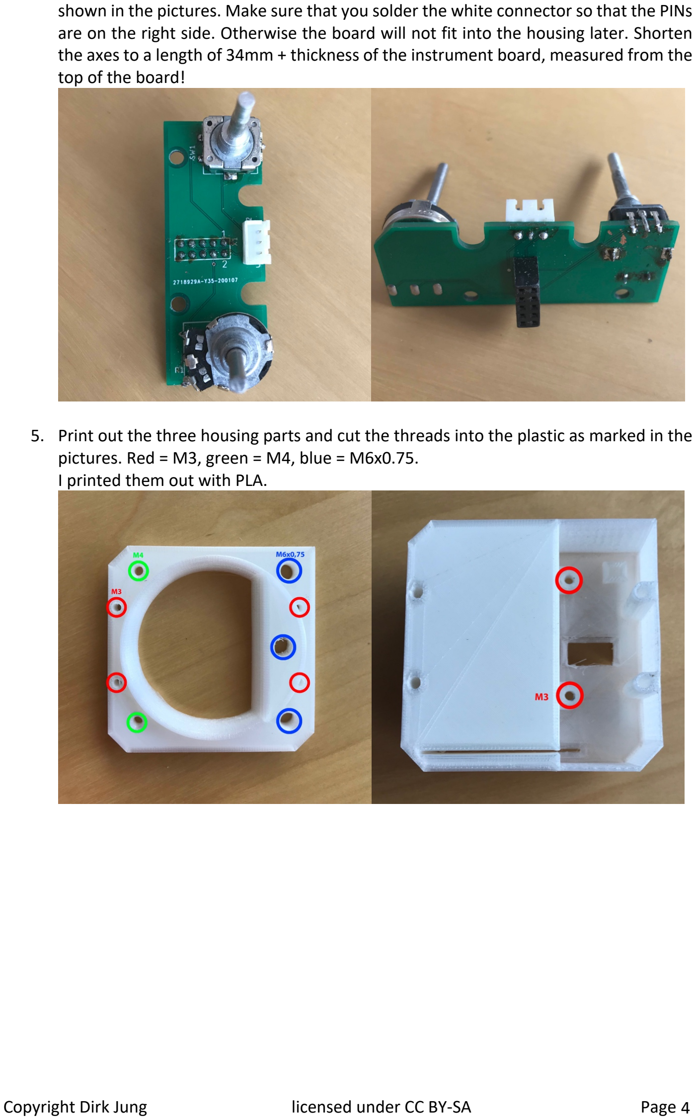
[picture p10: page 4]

shown in the pictures. Make sure that you solder the white connector so that the PINs are on the right side. Otherwise the board will not fit into the housing later. Shorten the axes to a length of 34mm + thickness of the instrument board, measured from the top of the board!

5. Print out the three housing parts and cut the threads into the plastic as marked in the pictures. Red = M3, green = M4, blue = M6x0.75.
I printed them out with PLA.


6. Cut two M4 threads in the speaker and fasten the speaker in the housing with 2 countersunk screws M4x8. Solder about 10cm long cables to connect the speaker beforehand. The speaker is only required if the FreeVario is to output the vario sound. If you want to continue using the vario sound from OpenVario, you can omit the speaker.
7. Crimp the connector to an approximately 5cm long, 3-pin cable and solder it to the toggle switch. Solder as space-saving as possible by soldering at an angle. Otherwise there will be a short circuit later between the solder joints and the contacts behind them on the PCB3. Make shrink wise the solder contacts!
The middle cable comes to the middle solder lug. Depending on how you solder the two outer cables, you will later have STF or Vario on top. If you solder the upper cable of the plug to the upper soldering tab of the toggle switch, and the lower cable of the plug to the lower soldering tab of the toggle switch, STF will be in the lower position of the toggle switch, and Vario in the upper. Automatic is in the middle.
8. Shorten the threads of the two M4 fastening screws to 3mm + instrument panel thickness. Work very precisely here, because if the screws are too long, press the display later and destroy it. It is best to screw the front panel into the cockpit on your own and check that the screws do not protrude into the area of the display.
9. Install the toggle switch and the display in the front panel.
10. Insert PCB3 in the middle part and screw tight with 2 screws M3x6. Tighten screws carefully, the threads are plastic!
11. Screw the front panel and middle section together using 4 countersunk screws M3x25. Connect the toggle switch beforehand and lead the FFC cable back through the slot. Tighten screws carefully, the threads are in plastic!
12. Now first test whether the two circuit boards can be easily pushed into the pot individually. Otherwise damage can occur later. If in doubt, rework the groove a little.

13. Carefully assemble PCB1 and PCB2, connect display, loudspeaker (do not interchange plus and minus) and connect PBC3. Close the clamping mechanism of the display cable very carefully with a small screwdriver or something similar. If you slip with your fingers or the wrong tool, it is easy for you to tear the ribbon cable.
14. The best thing to do now is to jump to the programming of the two ESP32 and then continue here.
15. Now push the housing pot carefully over the circuit boards. Make sure that the boards are in the rails and carefully guide the Western Digital socket through the rear wall.
16. Screw the housing parts together with 6 countersunk screws M3x6. Tighten screws carefully, the threads are in plastic!
17. Using the two fastening screws and the two banjo screws, install the Vario in the I-board, mount the knobs and connect the Vario. Tighten screws carefully, the threads are in plastic!
18. The connection cable has the same assignment on both sides, i.e. same color on the same PIN, like a normal LAN cable.

III. Programming and updating the two ESP32

With the small slide switch on the back of the FreeVario you can choose which of the two ESPs you want to describe (D=Display-ESP, S=Sound-ESP).

Variant 1: the software version of the FreeVario is lower than 1.2 or the ESPs have not yet been programmed:
1. Put the Binaries folder e.g. to the desktop
2. Download ALL the binaries from the website and save them in this folder
3. Open a terminal or the command prompt. There you can see if you can find the path to Binaries. For example, it is /Users/PC1/Desktop/Binaries/
4. In Arduino IDE click on Arduino -> settings.
5. Add the URL under "Additional Board Administrator URLs". If URLs have already been entered, add further URLs with commas and spaces. https://dl.espressif.com/dl/package_esp32_index.json
6. Also click here under "Verbose output during" "Upload".
7. Click Tools -> Board -> Board Administrator and search for ESP32.
8. Select „ESP32 by Espressif Systems“ and install.

9. You may have to install the driver for the serial adapter of the ESP. https://www.silabs.com/products/development-tools/software/usb-to-uart-bridge-vcp-drivers
10. Open and save a new sketch. Remember the name. To upload, set the following under Tools:
- Board: DOIT ESP32 DEVKIT V1
- Upload Speed: 115200
- Flash Frequency: 80MHz
- Core Debug Level: “none”
- Port: Check out which is added after connecting the ESP32 with the USB cable
11. Then upload the empty sketch. There is a very long command in white letters above the error message in the Arduino IDE, which is roughly as follows: /Users/PC1/Documents/Arduino/hardware/espressif/esp32/tools/esptool/esptool --chip esp32 --port /dev/cu.SLAB_USBtoUART --baud 115200 --before default_reset --after hard_reset write_flash -z --flash_mode dio --flash_freq 80m --flash_size detect 0xe000
/Users/PC1/Documents/Arduino/hardware/espressif/esp32/tools/partitions/boot_ap p0.bin 0x1000
/Users/PC1/Documents/Arduino/hardware/espressif/esp32/tools/sdk/bin/bootloader _dio_80m.bin 0x10000
/var/folders/6t/qjgfw2413f7ddnjzk_08btxw0000gp/T/arduino_build_661147/sketch_ dec30d.ino.bin 0x8000
/var/folders/6t/qjgfw2413f7ddnjzk_08btxw0000gp/T/arduino_build_661147/sketch_ dec30d.ino.partitions.bin
12. Copy this command, you need it to load the file onto the ESP32.
13. The first part of the command shows you where Arduino IDE creates its working directory. Remember the place. In this example it would be: /Users/PC1/Documents/Arduino
14. Change the command with your location where the Binaries folder is located. Also change the last two file names (see bold).

Display-ESP:
/Users/PC1/Documents/Arduino/hardware/espressif/esp32/tools/esptool/esptool --chip esp32 --port /dev/cu.SLAB_USBtoUART --baud 115200 --before default_reset --after hard_reset write_flash -z --flash_mode dio --flash_freq 80m --flash_size detect 0xe000 /Users/PC1/Desktop/Binaries/boot_app0.bin 0x1000 /Users/PC1/Desktop/Binaries/FreeVarioGauge.ino.bootloader.bin 0x10000 /Users/PC1/Desktop/Binaries/FreeVarioGauge.ino.bin 0x8000 /Users/PC1/Desktop/Binaries/FreeVarioGauge.ino.partitions.bin

Sound-ESP:
/Users/PC1/Documents/Arduino/hardware/espressif/esp32/tools/esptool/esptool --chip esp32 --port /dev/cu.SLAB_USBtoUART --baud 115200 --before default_reset --after hard_reset write_flash -z --flash_mode dio --flash_freq 80m --flash_size detect 0xe000 /Users/PC1/Desktop/Binaries/boot_app0.bin 0x1000 /Users/PC1/Desktop/Binaries/VarioSound.ino.bootloader.bin 0x10000 /Users/PC1/Desktop/Binaries/VarioSound.ino.bin 0x8000 /Users/PC1/Desktop/Binaries/VarioSound.ino.partitions.bin
15. Connect the ESP32 to the PC using the USB cable and open a terminal or the command prompt. Issue the appropriate command there.
16. After the upload is complete, the ESP32 restarts. The files then have to be uploaded to the memory of the respective ESP32.
17. The ESP32 Sketch Data Upload program currently only works up to Ardoino IDE 1.8.19!
18. Install ESP32 Sketch Data Upload. Download ESP32FS-1.1.zip from https://github.com/me-no-dev/arduino-esp32fs-plugin/releases/
19. On Mac, copy the extracted folder ESP32FS to /Documents/Arduino/tools.
20. Using Windows, copy the extracted folder ESP32FS to /Programs/Arduino/tools.
21. Download and unzip the sound_data.zip and display_data.zip files from the website. Go to the working directory of the Arduino IDE (e.g. /Users/PC1/Documents/Arduino) and there to the folder of the sketch you just created. Copy the unzipped data folder for the sound ESP or the display ESP here, depending on which one you want to upload to
22. Restart the Arduino IDE and open your newly created sketch.
23. IMPORTANT!! Make sure the serial monitor is closed.
24. Click on “ESP32 Sketch Data Upload” under Tools.
25. After the upload is complete, the ESP32 restarts and, if the display is already connected, you can now see the display of the vario gauge.
26. Now go back to point 13 of the assembly part of the instructions.

Variant 2: the software version of the FreeVario is at least 1.2:

Registering the ESPs in a WLAN
1. Switch on the FreeVario and, if possible, leave the OpenVario off. If it is not possible to switch on the devices independently of each other, end via the menu in OpenVario XCSoar. XCSoar should not try to communicate with the FreeVario during the update.
2. As long as the display shows the version number, you can switch to update mode.

3. To do this, move the toggle switch from the top to the bottom position, or from the bottom to the top position.
4. The soundboard acknowledges the update mode with a peep tone, the displayboard shows "starting update mode" on the screen.
5. If the two ESPs do not find a WLAN to which they can connect, start in access point mode, which means they provide a WLAN themselves.
6. As it takes a while to try to connect to a wireless network, this process may take around 1 minute.
7. What mode each ESP is in and what IP it can be reached on is displayed on the screen.
8. The access point of the soundboard is called "FreeVario_Soundboard", the access point of the displayboard is called "FreeVario_Displayboard"
9. Connect to one of the two access points with your computer or mobile phone and call up the respective IP displayed in the browser.
10. There you will find a list of the WiFi networks found. Choose the one you want the ESP to connect to and enter the appropriate SSID and WiFi password.
11. Now the connection data is saved in the EEPROM. Only the connection data for a WLAN can be saved there. If you connect to someone else, the old connection data will be deleted.
12. Restart the FreeVario, go back to update mode and repeat steps 9 - 11 with the other access point.
13. You don't have to repeat steps 1 - 12 in the future if you stay in the same WLAN.

ESPs already connect to a WLAN
14. Download the binary files VarioSound.ino.bin and FreeVarioGauge.ino.bin from FreeVario.de and save them on your device.
15. Restart the FreeVario and return to update mode.
16. Now both ESPs connect to the selected WLAN. Connect your computer or mobile phone to this WLAN as well and call up one of the two IPs shown on the display in the browser.
17. Enter "Sound" for the password and login on the Soundboard.
18. Enter "Display" for the password and login on the display board.
19. Select the VarioSound.ino.bin file for the Soundboard and the FreeVarioGauge.ino.bin file for the Displayboard and click on Update.

20. The update takes about 1 minute and the successful completion is indicated by a restart of the display on the display board. Unfortunately, there is no feedback from the soundboard.
21. Restart the FreeVario, go back to update mode and repeat steps 16 - 20 for the other ESP.
22. The process is complete after restarting the FreeVario.

Variant 3: the software version of the FreeVario is at least 1.2.1:
1. Download the binary files VarioSound.ino.bin and FreeVarioGauge.ino.bin from FreeVario.de and save them on your device.
2. Switch on the FreeVario and, if possible, leave the OpenVario off. If it is not possible to switch on the devices independently of each other, end via the menu in OpenVario XCSoar. XCSoar should not try to communicate with the FreeVario during the update.
3. As long as the display shows the version number, you can switch to update mode.
4. To do this, move the toggle switch from the top to the bottom position, or from the bottom to the top position.
5. The soundboard acknowledges the update mode with a peep tone, the displayboard shows "starting update mode" on the screen.
6. Now the display board provides the WLAN FV_Displayboard and the soundboard provides the WLAN FV_Soundboard. The password is 12345678 in each case.
7. The ESP32's WLAN generates noise in the audio amplifier, this is unfortunately normal.
8. If you have connected to one of the two WLANs, you can call up the update page of the respective board in your browser.
9. Enter FreeVario_Displayboard.local or FreeVario_Soundboard.local as the URL, or alternatively the IP shown on the display.
10. Select the VarioSound.ino.bin file for the Soundboard and the FreeVarioGauge.ino.bin file for the Displayboard and click on Update.
11. The update takes about 1 minute and successful completion is indicated by a restart of the display on the display board. Unfortunately, there is no feedback from the soundboard.
12. Restart the FreeVario, go back to update mode and repeat steps 16 - 20 for the other ESP.
13. The process is complete after restarting the FreeVario.

IV. Backing up and restoring your settings

1. Save the settings:

Variant 1: the original menu is used:
- Back up the .xcsoar folder from the old system
- Boot OpenVario and go to the menu. Select "Exit to the shell" and confirm with Yes. Connect your USB stick to manage the OpenVario and a USB keyboard. Enter the following commands.
- mkdir /tmp/USB
- mount /dev/„USB-Stick“ /tmp/USB (/„USB-Stick“ usually is /dev/sda1)
- cp -r .xcsoar /tmp/USB (takes a bit of time!)
- cd /tmp/USB
- mv .xcsoar xcsoar
- rm -r openvario/upload/xcsoar
- mv xcsoar openvario/upload/
- Save the value for calibrating the voltage display (if you have calibrated it at all, skip step otherwise):
- Boot OpenVario and go to the menu. Select "Exit to the shell" and confirm with Yes. Connect a USB keyboard and enter the following commands.
- nano /opt/conf/sensord.conf
- write down the value for the "voltage_config" variable. For me it was „voltage_config 1592.4 4.54545“.
- 1592.4 is the scaling factor, 4.54545 is the offset. The formula to convert the value of the AD converter into the voltage value is:
- U = (value AD converter / scaling factor) + offset
- Save the WiFi settings:
- Copy the folder /var/lib/connman to the USB stick, which is already mounted.
- cp -r /var/lib/connman /tmp/USB

Variant 2: the new menu from Kedder is used:
- Insert an empty FAT32 formatted USB stick into the OpenVario
- Start the OpenVario and select “Applications” -> “Backup” -> “Backup” in the menu
- Everything important is now automatically backed up
2. Upload your saved data to the OpenVario:

Variant 1: the original menu is used:
- Insert the new SD card into the OpenVario and start. Then go back to the OpenVario menu.
- Click "Copy file to and from OpenVario" -> "Upload files from USB to XCSoar". This will restore all of your settings. Wait until “done !!” is shown.
- Then set the desired orientation of the display under "Update, Settings, ..." -> "System Settings" with "Set rotation of the display".
- If necessary, select “Calibrate Touch” under “Update, Settings,…”.
- Select “Calibrate Sensors” under “Update, Settings,…”.

- Finally, set the language under "Update, Settings, ..." -> "System Settings" -> "Set language used for XCSoar".
- Back to the main menu with ESC and select "Restart" and confirm with Yes.
- Restore the voltage display calibration:
- nano /opt/conf/sensord.conf
- „voltage_config” reset to the noted values
- Restore backup of old WiFi settings:
- Copy the connman folder saved on the USB stick back into the /var/lib directory
- mkdir /tmp/USB
- mount /dev/„USB-Stick“ /tmp/USB (/„USB-Stick“ usually is /dev/sda1
- cp -r /tmp/USB/connman /var/lib
- Set up WiFi again if there is no backup of the old settings:
- Boot OpenVario and go to the menu. Select "Exit to the shell" and confirm with Yes. Connect a USB keyboard and enter the following commands.
- connmanctl
- enable wifi
- scan wifi
- services
- agent on
- connect wifi_...
- Enter password

Variant 2: the new menu from Kedder is used:
- Insert the USB stick with your backup into the OpenVario
- Start the OpenVario and select “Applications” -> “Backup” -> “Restore” in the menu
- Everything important is now automatically restored
V. Install the new OV image including XCSoar with FreeVario driver
1. From the official Image 21033 of OpenVario, the FreeVario driver is integrated in the image. So you are no longer dependent on using images from FreeVario.de. If you have already installed an image higher the 21032, you can connect the FreeVario directly to your OpenVario without making any changes at the software.
2. Install the new image:

Variant 1: Use a new SD card (secure method)
- Use a Linux PC to write the new image to another SD card. So you can be sure that on the old map there is still a working system in case something goes wrong.
- unzip the image first:
- gunzip "Path_to_Image"
- e.g .: gunzip /home/USER/Schreibtisch/OpenVario-linux-openvario-image-testing-glibc-ipk-20149-openvario-7-PQ070.rootfs.img.gz

- dd if=“ Path_to_image“ of=/dev/„ new_SD card “
- z.B.: dd if=OpenVario_new.img of=/dev/sda

Variant 2: Overwrite old SD card (insecure method)
- In the main directory of the USB stick "openvario" you put the recovery file "ov-
recovery.itb", | which | you | can | download | on | the | FTP | server
(ftp://ftp.openvario.org/recovery).
- IMPORTANT!! If you do not want to perform a recovery, the file "ov-recovery.itb" must be renamed, e.g. in "ov-recovery.xxx".
- Copie the image to be installed as a .gz file to the USB stick in the images subfolder
- Insert the USB stick into the OpenVario and boot.
- The recovery menu is shown in red. Remember that all files in OpenVario will be deleted when you restore!
- Select "Write image to SD Card" and then "Update complete SD Card".

VI. Install XCSoar incl. FreeVario driver without reinstalling the OV image

1. If you don't want to reinstall the complete image of OV, but only want to replace the version of XCSoar, you can do that as described below. Your settings in XCSoar remain completely intact. I would always create a backup file of the SD card beforehand. Something always can go wrong!
2. Copy the new version of the installation file from XCSoar to a USB stick, select "Exit to the shell" in the OpenVario menu. Find the path of the USB stick with fdisk -l (e.g. /dev/sda1).
3. mkdir /tmp/USB
4. mount /dev/sda1 /tmp/USB
5. cd /tmp/USB
6. opkg remove xcsoar
7. opkg install xcsoar*.ipk
8. Set the language in the OpenVario menu again and reboot.

VII. Switch off the vario sound from OpenVario

### 1. Skip this section completely if you want to continue using the vario sound from

OpenVario. If you wanted the FreeVario to make the sound, you have to work through this section.

2. Choose "Exit to the shell" from the OpenVario menu and enter the command "systemctl disable variod" to switch off the vario sound from OpenVario.
3. Reboot OpenVario.
4. Changes the port of NMEA port A from 4352 to 4353.
5. If vario sound can still be heard in XCSoar, it will be generated by XCSoar.
6. At System -> Display -> Audio Vario set Audio Vario to ON and set volume at 0%. Confirm with Close.

VIII. Settings for a doubleseater

1. To connect the front and rear OpenVario to each other, you have to use a crossed cable. That means you have to swap PINs 5 and 6 for RX and TX on one connector.
2. The front device is set to the RJ45 socket to be used, e.g. ttyS3, NMEA output is set as driver, the baud rate e.g. to 38400 (it must be the same in front and in the back!)
3. The rear device is also set to the RJ45 socket to be used, e.g. ttyS3, OpenVario is set as the driver, and the baud rate must be set in the same way as the front device.

IX. Blocking the standard profile for club use

1. Go to the console in the main menu of the OpenVario, in which you select "Exit to Shell".
2. Go to the directory in which the profiles are saved with "cd .xcsoar".
3. By default, the profile is called openvario.prf. I renamed it to clubprofile.prf (mv openvario.prf clubprofile.prf)
4. Lock the profile with the following command:
chattr +i clubprofile.prf
5. Unlock the profile with the following command: chattr -i clubprofile.prf

X. Settings in XCSoar
1. Click Config. -> Devices, select a free device from A, B, C or D and select Edit.
2. You should assign the connections so that the Flarm is above the FreeVario.
3. Select the port, where the electronical vario is connected with (e.g. ttyS1).
4. Baud rate is 115200, Driver is FreeVario, confirm with OK and Close.

XI. Settings for the stick remote control with FreeVario

In order to be able to use the STF switch to control the FreeVario in automatic mode, a few settings must be made. The changeover from Vario to STF, or vice versa, then works as follows:
1. priority has the toggle switch of the FreeVario. If STF or Vario is selected with it, the FreeVario is set to the respective mode. If the toggle switch of the FreeVario is on automatic, the 2nd priority comes into play.
2. The stick remote control has priority. A short click activates Vario, a long click STF and a double click the automatic mode. The mode set with the stick remote control is sent to the FreeVario and to the OpenVario to change the tone. If the stick remote control is also in automatic mode, the third priority is active.
3. Depending on which option was selected in the menu under STF, priority is now given to XCSoar or a switch connected to the flaps. Here, too, only the FreeVario is being switched at the moment. A command to the OpenVario to switch the sound does not work at the moment.

Important!! Sets in XCSoar OpenVario on device A and FreeVario on device B. Otherwise it won't work !!

1. The image of the FreeVario page must be newer than 22028 on the OpenVario. How to do this is given in Chapter V.
2. On the FreeVario, the ESPs of the display board and the soundboard must be updated to at least version 1.1.4. How to do this is in Chapter III.
3. If you use the openvario.xci file originally from the image and have not changed it to sort the menu or anything similar, you don't need to do anything here. Be careful, if you import a backup, the openvario.xci file will automatically be overwritten with your old version. Then you should first change the file in your backup with a text editor. The text editor is not allowed to do any text formatting, I use VSCode for that. If you use your own file, you must also make the following changes:

mode=default
type=key
data=V event=SendNMEAPort1 POV,C,VAR event=StatusMessage Vario Mode

mode=default
type=key
data=S
event=SendNMEAPort1 POV,C,STF event=StatusMessage Speed to Fly Mode
Change to:

mode=default
type=key
data=V
#event=SendNMEAPort1 POV,C,VAR event=SendNMEAPort2 PFV,REM,C #event=StatusMessage Vario Mode

mode=default
type=key
data=S
#event=SendNMEAPort1 POV,C,STF event=SendNMEAPort2 PFV,REM,S #event=StatusMessage Speed to Fly Mode

mode=default
type=key
data=A
event=SendNMEAPort2 PFV,REM,A event=StatusMessage Automatic Mode
4. If you use a variant of the stick remote control with a toggle switch, you can skip the remaining menu items. If you have a version with a button, you have to update your stick remote control.
5. How it works, Stefan Langer has published here in a video: https://youtu.be/vwJqPAwFBlU
6. To do this, install the Arduino IDE on your PC (https://www.arduino.cc/en/software)
7. Then download the file bounce.zip in our download area, unzip it and save the unzipped folder in the library directory of the Arduino IDE. Where you can find the library directory depends on the operating system on your computer. It's best to google it.
8. Then download the file Stick_Remote_Control_FV.zip from us and unzip it
9. Opens the Stick_Remote_Control_FV.ino file

10. Click on Tools in the Arduino IDE and select the Arduino Leonardo at Board
11. As the port you choose the one that came last when you connected the stick remote control to the computer via the USB cable
12. Click on “Upload” and that's it

XII. Settings for the stick remote control without FreeVario

If you import a backup of your OpenVario settings, the openvario.xci file will automatically be overwritten with your old version and should be set correctly again. If you use the original openvario.xci file from the image instead, you have to make a few adjustments. To make changes in the openvario.xci file, you must use a text editor that does not do text formatting. I use VSCode for this. The following changes must be made:

mode=default
type=key
data=V
#event=SendNMEAPort1 POV,C,VAR event=SendNMEAPort2 PFV,REM,C #event=StatusMessage Vario Mode

mode=default
type=key
data=S
#event=SendNMEAPort1 POV,C,STF event=SendNMEAPort2 PFV,REM,S #event=StatusMessage Speed to Fly Mode

Change to:

mode=default
type=key
data=V
event=SendNMEAPort1 POV,C,VAR #event=SendNMEAPort2 PFV,REM,C event=StatusMessage Vario Mode

mode=default
type=key
data=S
event=SendNMEAPort1 POV,C,STF #event=SendNMEAPort2 PFV,REM,S event=StatusMessage Speed to Fly Mode

XIII. Installation of the new OpenVario menu from Kedder

1. The OpenVario must be connected to the Internet and a keyboard must be connected.
2. Start OpenVario and go to the OV menu. Select "Exit to the shell" and confirm with Yes.
3. Enter the following command there: - | wget https://raw.githubusercontent.com/kedder/openvario-shell/master/scripts/openvario-shell-install.sh -
| O - | sh
4. Use ESC to return to the main menu and select "Restart" and confirm with Yes. The
new menu is now used.
5. If the menu is to be uninstalled again, use the command: - wget https://raw.githubusercontent.com/kedder/openvario-shell/master/scripts/openvario-shell-uninstall.sh -O - | sh
6. The menu can be updated via the menu itself or using the shell. The following commands are required in the shell: - opkg update
- opkg upgrade

XIV. Update maps, airspaces etc. with the new menu from Kedder

1. Create a USB stick with your backup as described in Chapter IV, Variant 2
2. Put the stick in your PC and go to the directory /openvario/backup/home/root/.xcsoar
3. Put the files you want to update here
4. Insert the stick into the OpenVario
5. Start the OpenVario and select “Applications” -> “Backup” -> “Restore” from the menu
6. All files that are newer than those on the OpenVario are updated

XV. Using an LTE stick

1. If a Freevario image larger than 22163 is used on the OpenVario, it can go online with an LTE stick (Huawei E3372h-320).
2. The PIN query must be switched off for the SIM card

3. Simply plug the stick into a free USB port and when it is connected to the mobile network, you can go online via LTE and download weather information from PCMet, for example

XVI. Installation
1. USB-C port to update the two ESP’s
2. 3.5mm jack socket for external speaker
3. Plug for speed-to-fly switch/flap switch and PTT switch
a. PTT
b. STF switch
c. STF switch
4. Switch which ESP should be updated
5. IGC plug for OpenVario

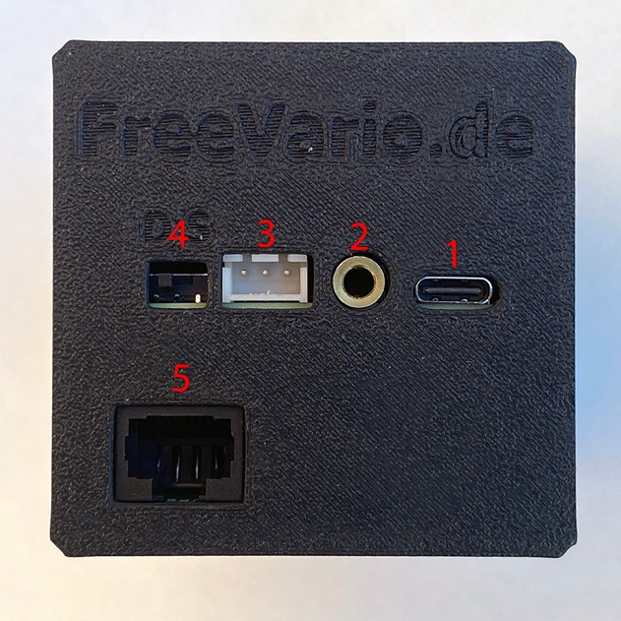
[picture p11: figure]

1. Slide the two hollow screws over the axis of the encoder or potentiometer and screw them to the FreeVario
2. It is essential to shorten (3mm + instrument panel thickness) the two M4 screws before assembly and check for correct length, otherwise the display will be destroyed!
3. Fasten the FreeVario with the M4 screws
4. Tighten the two rotary knobs. Make sure that the encoder button has enough space to the rear for the push button to work
5. Attach the cover caps to the rotary knobs
6. Connect FreeVario to OpenVario with an IGC-compliant cable. If the FreeVario is connected to OpenVario, a 1:1 cable is used. If it is connected to Larus, a crossover cable must be used.
7. If necessary, connect the flap switch (closed, if the vario is to be set to STF) and PTT button to the three-pin plug
8. To avoid reception problems, the antennas of other devices should be installed as far away as possible from the FreeVario

Bis Hardwareversion V2.0
1. Audio +
2. NC
3. Audio -

Ab Hardwareversion V2.1
1. Audio +
2. Audio -
3. GND


XVII.Disclaimer

The vario gauge is not EASA or FAA certified. Note that this is exactly the same for all the fancy commercial electronic varios and flight computers you are probably used to.

If would you like to know, if you are allowed to use it legally at your glider, ask this question to your airworthiness inspector. Can you legally install any other big brand (as well, non certified) vario gauges? If yes, you should also be able to legally install this vario gauge. If you are under EASA rules see CS-STAN, standard change CS-SC402a.

This instrument is a craft project and not an aviation-approved instrument. I explicitly point out that the use is made under exclusion of any warranty at your own risk!

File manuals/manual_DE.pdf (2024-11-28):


Copyright Dirk Jung | licensed under CC BY-SA | Page 1

## Bedienungsanleitung für das FreeVario

## Inhaltsverzeichnis

Rev. 1.8 (08.2024)

I. Bedienung des FreeVarios
1. Mit Hilfe des Kippschalters wird das Vario auf SpeedToFly (STF) oder Vario-Modus (Vario) umgeschaltet. In der Mittelstellung ist der Automatikmodus aktiv. Im Menü kann unter dem Punkt STF (ab V2.2) zwischen den Optionen OV und Flaps gewählt werden. Bei OV bestimmt XCSoar, bei Flaps ein extern angebrachter Schalter im Automatikmodus, ob Vario oder STF aktiv sein soll. Der externe Schalter kann beispielsweise mit den Wölbklappen verbunden werden, so dass je nach Klappenstellung automatisch zwischen Vario und STF umgeschaltet wird. Wenn das Vario auf STF gestellt werden soll, sollte dieser Schalter geschlossen sein. Alternativ könnte auch ein Kippschalter am Knüppel verwendet werden, wenn der Kippschalter im FreeVario nicht benutzt werden soll. Den Kippschalter im FreeVario dann am besten nicht einbauen.
2. Ist der Modus STF aktiv, geben die Ziffern am farbigen Bogen mit 10 multipliziert die Differenz zwischen true Airspeed und Sollfahrt an und oben wird das netto Steigen angezeigt.
z.B.: Im Modus STF steht der farbige Balken bei +3. Damit ist die true Airspeed um 30km/h höher als die Sollfahrt.
Ist der Modus Vario aktiv, wird oben das über 30s integrierte Steigen angezeigt.
3. Mit dem Drehencoder oben wird im Normalmodus der McCready-Wert eingestellt und an XCSoar gesendet.
4. Wird der Pushbutton des Drehencoders für mehr als 0,5s gedrückt, wird das Menü aktiviert, und die Zeile, in der die Höhe angezeigt wird, wird rot. Durch Drehen am Encoder kann die Zeile mit der Geschwindigkeitsanzeige oder mit dem McCready-Wert ausgewählt werden. Durch ein kurzes Drücken des Pushbuttons wird der ausgewählte Menüpunkt aktiviert. Im Höhenmenü kann nun durch Drehen zwischen Höhe über NN (MSL) und Höhe über Grund (AGL), im Geschwindigkeitsmenü kann zwischen Groundspeed (GS) und true Airspeed (TAS) ausgewählt werden. Ein weiteres kurzes Drücken des Pushbuttons wählt die aktuelle Einstellung aus und im Display werden die gewünschten Werte angezeigt.
5. Eine Besonderheit stellt die untere Anzeige für den McCready dar. Hier kann bei aktiviertem Menü durch Drehen zwischen QNH, Bug, Dämpfung (ATT), Mute, Wind und STF ausgewählt werden. Unter dem Punkt Dämpfung lässt sie einstellen, wie stark die STF-Anzeige gedämpft werden soll. Ein kurzes Drücken des Pushbuttons aktiviert die gewünschte Option, und durch Drehen am Encoder wird der Wert eingestellt und an XCSoar gesendet. Ein weiteres kurzes Drücken des Pushbuttons schließt den Menüpunkt und im Display wird wieder der McCready-Wert angezeigt.
6. Wird das Menü für mindestens 10s nicht benutzt, wird das Menü automatisch wieder verlassen, und die zu diesem Zeitpunkt ausgewählte Einstellung übernommen.
7. Die Einstellungen der Geschwindigkeits- bzw. Höheneinstellung, sowie der Dämpfungsfaktor und die Einstellung für Mute, Wind und STF werden im Gerät gespeichert.

8. Die 3,5mm Klinkenbuchse auf der Rückseite dient zum Anschließen eines externen Lautsprechers, um einen besseren Sound zu erhalten. Ist der externe Lautsprecher angeschlossen, wird der interne automatisch deaktiviert.
9. Wenn der PIN „a“ des dreipoligen Steckers mit der Sendetaste verbunden wird, wird der Variosound beim Funken automatisch stumm geschaltet. Falls das Funkgerät und das FreeVario an unterschiedlichen Batterien angeschlossen sind, muss der Minuspol beider Batterien miteinander verbunden werden! Wird das Funkgerät z.B. zum Sparen von Strom ausgeschaltet, ist das für das FreeVario das gleiche, als würden man die Sendetaste drücken. Damit das FreeVario aber weiterhin den Varioton ausgibt, gibt es im untersten Menüpunkt die Option Mute. Sie kann auf ON bzw. OFF gestellt werden. Schaltet man sie auf OFF, ist die Funktion deaktiviert. Bei einem Neustart des FeeVarios ist sie automatisch wieder aktiv.

II. Einstellungen in XCSoar

1. Unter Konfig. -> NMEA-Anschluss einen freien Anschluss aus A, B, C oder D auswählen und auf Bearbeiten klicken.
2. Du Zuordnung der Anschlüsse sollte so gewählt werden, dass das Flarm über dem FreeVario steht.
3. Bei Anschluss wählt ihr den Anschluss, an dem das e-Vario angeschlossen wurde (z.B. ttyS1).
4. Baudrate ist 115200, Treiber ist FreeVario, mit OK und Schließen bestätigen.

III. Benutzen der Knüppelfernbedienung
Um mit der Knüppelfernbedienung das FreeVario zwischen STF und Vario Modus umstellen zu können, sind ein paar Änderungen notwendig, die im Installationshandbuch beschrieben sind. Ist alles korrekt installiert, funktioniert die Umschaltung wie folgt:
1. Priorität hat der Kippschalter des FreeVarios. Wird mit ihm STF oder Vario gewählt, wird das FreeVario auf den jeweiligen Modus gestellt. Steht der Kippschalter des FreeVarios auf Automatik, kommt die 2. Priorität zum Tragen.
2. Priorität hat die Knüppelfernbedienung. Ein kurzer Klick aktiviert Vario, ein langer Klick STF und ein Doppelklick den Automatikmodus. Der mit der Knüppelfernbedienung eingestellte Modus wird an das FreeVario und an das OpenVario zum Ändern des Tons geschickt. Ist auch die Knüppelfernbedienung im Automatikmodus, ist die dritte Priorität aktiv.
3. Priorität hat, je nach dem welche Option im Menü unter STF gewählt wurde, jetzt XCSoar oder ein an den Wölbklappen angeschlossener Schalter. Auch hier wird im Moment nur das FreeVario umgeschaltet. Ein Befehl an das OpenVario zum Umschalten des Tons geht im Moment nicht.

Wichtig!! Stellt in XCSoar auf Device A OpenVario und auf Device B FreeVario ein. Ansonsten funktioniert es nicht!!

IV. Abschalten des Variotons vom OpenVario

### 1. Überspringt diesen Abschnitt komplett, wenn ihr den Varioton von OpenVario

weiter nutzen wollt. Wollte ihr das FreeVario den Ton ausgeben lassen, müsst ihr diesen Abschnitt durcharbeiten.

2. Geht über das OpenVario Menü auf „Exit to the shell“ und gebt dort den Befehl „systemctl disable variod“ ein, um den Varioton von OpenVario abzuschalten.
3. Das OpenVario neu starten.
4. Ändert den Port des NMEA-Anschlusses A von 4352 auf 4353.
5. Sollte weiterhin in XCSoar ein Varioton zu hören sein, wird dieser vom XCSoar erzeugt.
6. Unter System -> Anzeige -> Audio-Vario Audio-Vario auf Ein und die Lautstärke auf 0% stellen. Mit Schließen bestätigen.
V. Ausschlusserklärung

Das e-Vario ist nicht EASA- oder FAA-zertifiziert. Dies gilt im Übrigen für viele kommerzielle e-Varios und Flugcomputer, die ihr wahrscheinlich gewohnt seid.

Wenn ihr wissen möchtet, ob ihr dieses e-Vario in eurem Segelflugzeug legal verwenden dürft, wendet euch an euren Prüfer. Könnt ihr legal einen anderen (auch nicht zertifizierten) Flugcomputer anderer Hersteller installieren? Wenn ja, solltet ihr auch dieses e-Vario legal installieren dürfen. Wenn euer Flugzeug unter die EASA-Regeln fällt, lest CS-STAN, Standardänderung CS-SC402a.

Es handelt sich bei diesem Instrument um ein Bastelprojekt und nicht um ein luftfahrtzugelassenes Instrument. Ich weise ausdrücklich darauf hin, dass der Einsatz unter Ausschluss jeglicher Gewährleistung auf eigenes Risiko erfolgt!

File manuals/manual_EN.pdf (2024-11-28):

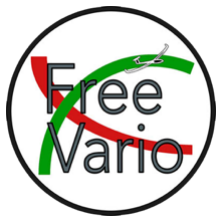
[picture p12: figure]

Copyright Dirk Jung | licensed under CC BY-SA | Page 1

## Operating instructions for the FreeVario

## Table of Contents

Rev. 1.8 (08.2024)

I. Operating the FreeVario
1. Using the toggle switch, the Vario is switched to SpeedToFly (STF) or Vario mode (Vario). Automatic mode is active in the middle position. In the menu under STF (from V2.2) you can choose between the options OV and Flaps. In OV, XCSoar determines whether Vario or STF should be active, and in Flaps, an externally mounted switch in automatic mode. The external switch can, for example, be connected to the flaps, so that the Vario and STF are automatically switched depending on the flap position. If the vario is to be set to STF, this switch should be closed. Alternatively, a toggle switch on the stick could be used if the toggle switch should not be used in the FreeVario. In that case it is best not to install the toggle switch in the FreeVario.
2. If STF mode is active, the digits on the colored arc multiplied by 10 indicate the difference between true airspeed and speed to fly and the netto climb rate is shown at the top.
e.g .: in STF mode the colored bar is at +3. The true airspeed is 30km/h higher than speed to fly.
If the Vario mode is active, the climb rate integrated over 30 seconds is displayed at the top.
3. With the rotary encoder above, the McCready value is set in normal mode and sent to XCSoar.
4. If the push button of the rotary encoder is pressed for more than 0.5s, the menu is activated and the line in which the height is displayed turns red. The line with the speed display or with the McCready value can be selected by turning the encoder. The selected menu item is activated by briefly pressing the push button. In the high menu you can now choose between altitude above sea level (MSL) and altitude above ground (AGL), in the speed menu you can choose between ground speed (GS) and true air speed (TAS). Another short press on the push button selects the current setting and the desired values are shown in the display.
5. A special feature is the lower display for the McCready. Here you can choose between QNH, bug, damping (ATT), mute, wind and STF by turning the menu. Under damping you can set how much the STF display should be damped. A short press on the push button activates the desired option and turning the encoder sets the value and sends it to XCSoar. Another short press on the push button closes the menu item and the McCready value is shown in the display again.
6. If the menu is not used for at least 10s, the menu is automatically exited and the setting selected at this point is adopted.
7. The settings for speed or altitude setting, as well as damping factor, mute, wind and STF setting are saved in the device.
8. The 3.5mm jack socket on the back is used to connect an external speaker to get a better sound. If the external speaker is connected, the internal one is automatically deactivated.

9. If the PIN “a” of the three-pole plug is connected to the PTT switch, the Variosound is automatically muted when you are talking. If the radio and the FreeVario are connected to different batteries, the negative pole of both batteries must be connected! If the radio is switched off to save electricity, it is the same for the FreeVario as pressing the PTT switch. So that the FreeVario continues to output the vario tone, there is the Mute option in the bottom menu item. It can be set to ON or OFF. If you switch it OFF, the function is deactivated. It is automatically reactivated when the FeeVario is restarted.

II. Settings in XCSoar

1. Click Config. -> Devices, select a free device from A, B, C or D and select Edit.
2. You should assign the connections so that the Flarm is above the FreeVario.
3. Select the port, where the electronical vario is connected with (e.g. ttyS1).
4. Baud rate is 115200, Driver is FreeVario, confirm with OK and Close.

III. Using the stick remote control
In order to be able to switch the FreeVario between STF and Vario mode with the stick remote control, a few changes are necessary, which are described in the installation manual. If everything is installed correctly, the switchover works as follows:
1. priority has the toggle switch of the FreeVario. If STF or Vario is selected with it, the FreeVario is set to the respective mode. If the toggle switch of the FreeVario is on automatic, the 2nd priority comes into play.
2. The stick remote control has priority. A short click activates Vario, a long click STF and a double click the automatic mode. The mode set with the stick remote control is sent to the FreeVario and to the OpenVario to change the tone. If the stick remote control is also in automatic mode, the third priority is active.
3. Depending on which option was selected in the menu under STF, priority is now given to XCSoar or a switch connected to the flaps. Here, too, only the FreeVario is being switched at the moment. A command to the OpenVario to switch the sound does not work at the moment.

Important!! Setsin XCSoar OpenVario on device A and FreeVario on device B. Otherwise it won't work !!

IV. Switch off the vario sound from OpenVario

### 1. Skip this section completely if you want to continue using the vario sound from

OpenVario. If you wanted the FreeVario to make the sound, you have to work through this section.

2. Choose "Exit to the shell" from the OpenVario menu and enter the command "systemctl disable variod" to switch off the vario sound from OpenVario.
3. Reboot OpenVario.
4. Changes the port of NMEA port A from 4352 to 4353.
5. If vario sound can still be heard in XCSoar, it will be generated by XCSoar.
6. At System -> Display -> Audio Vario set Audio Vario to ON and set volume at 0%. Confirm with Close.
V. Disclaimer

The vario gauge is not EASA or FAA certified. Note that this is exactly the same for all the fancy commercial electronic varios and flight computers you are probably used to.

If would you like to know, if you are allowed to use it legally at your glider, ask this question to your airworthiness inspector. Can you legally install any other big brand (as well, non certified) vario gauges? If yes, you should also be able to legally install this vario gauge. If you are under EASA rules see CS-STAN, standard change CS-SC402a.

This instrument is a craft project and not an aviation-approved instrument. I explicitly point out that the use is made under exclusion of any warranty at your own risk!

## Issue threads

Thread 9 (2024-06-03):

SPIFFS OTA update

mk-it-easy, 2024-06-03:
spiffs should be updatable OTA
- FreeVarioGauge

mk-it-easy, 2024-06-10:
- version should be integrated into spiffs data upon creation of the spiffs image
- upon reading an older version or a missing file, the device should enter upgrade mode automatically

Closed 2025-05-23.

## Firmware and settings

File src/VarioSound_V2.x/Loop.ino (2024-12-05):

void loop() {
  //***********************************
  //****  Analysis automatic mode  ****
  //***********************************
  varioSchalter_state = digitalRead(Varioschalter);
  stfSchalter_state = digitalRead(STFSchalter);
  stfAuto_state = digitalRead(STFAuto);
  xc_WK_state = valueSTFAsInt;

  if (SourceIsXCSoar == true) {
    if ((varioSchalter_state == 1) && (stfSchalter_state == 1)) {
      digitalWrite(STF_AUTO, HIGH);
    }
    else {
      digitalWrite(STF_AUTO, LOW);
    }
    if (((varioSchalter_state == 1) && (stfSchalter_state == 1) && (rem == "A") && (xc_WK_state == 0) && (stfAuto_state == 1)) ||
        ((varioSchalter_state == 1) && (stfSchalter_state == 1) && (rem == "A") && (xc_WK_state == 1) && (mod == "C")) ||
        ((varioSchalter_state == 1) && (stfSchalter_state == 1) && (rem == "C")) ||
        ((varioSchalter_state == 0) && (stfSchalter_state == 1))) {
      digitalWrite(STF_MODE, LOW);
    }
    else if (((varioSchalter_state == 1) && (stfSchalter_state == 1) && (rem == "A") && (xc_WK_state == 0) && (stfAuto_state == 0)) ||
             ((varioSchalter_state == 1) && (stfSchalter_state == 1) && (rem == "A") && (xc_WK_state == 1) && (mod == "S")) ||
             ((varioSchalter_state == 1) && (stfSchalter_state == 1) && (rem == "S")) ||
             ((varioSchalter_state == 1) && (stfSchalter_state == 0))) {
      digitalWrite(STF_MODE, HIGH);
    }
  }
  else if (SourceIsLarus == true) {
    digitalWrite(STF_MODE, LOW);
    digitalWrite(STF_MODE, LOW);
  }
  UpdateMode();
  SerialScan ();
}

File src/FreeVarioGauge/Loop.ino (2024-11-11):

void loop() {
  if (showBootscreen) {
    UpdateMode();
  }
  else {
    EncoderReader();
    Menu ();
    if (millis() - stayAlive >= 9000) {
      String muteStr = ("$PFV,S,S," + String(valueMuteAsInt) + "*");
      int checksum = calculateChecksum(muteStr);
      Serial2.printf("%s%X\n", muteStr.c_str(), checksum);
      stayAlive = millis();
    }
  }
}

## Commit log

2022-08-06 fix a bug with sound
    [VarioSound.ino]
2023-08-04 Change WiFi mode
    The update via WiFi is now much easier, since the FreeVario offers the possibility to connect the two boards directly and upload the update without any problems.
    [FreeVarioGauge.ino, VarioSound.ino]
2023-08-11 finally bug fix for V1.2.1
    [FreeVarioGauge.ino, VarioSound.ino]
2023-08-20 Bug fix Wifi connection
    [FreeVarioGauge.ino]
2023-08-20 Bug fix STF at ground
    [FreeVarioGauge.ino, VarioSound.ino]
2023-11-14 Bugfix: Mosquito value was not displayed correctly
    [FreeVarioGauge.ino, VarioSound.ino]
2024-04-06 including external wind direction wind speed
    FreeVario is able to show external wind direction and wind speed from device like Larus. Larus can used as source for FreeVario, too.
2024-04-07 fix(): use enum type
    [Setup.ino]
2024-04-22 fix(boot_logo): use convenience pushImage
    [ShowBootScreen.ino]
2024-04-26 Correct boot logo when BMP is not available
    [ShowBootScreen.ino]
2024-05-23 bugfix: vario sound was missing if Larus is source
    [SerialScan.ino]
2024-05-25 solved some bug with Larus connection
    solved more bug with Larus connection
    [Calculations.ino, Loop.ino, SerialScan.ino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]
2024-07-17 Change wind color and fix STF
    [BMPReader.ino, FreeVarioGauge.ino, SerialScan.ino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]
2024-08-04 including STF-Mode to the menu
    In automatic mode for changing STF and Vario XCSoar or a flaps switch are responsible to change the vario-mode. Now this can be adjusted at the menu and the switch is no longer necessary
    [ChangeValues.ino, FreeVarioGauge.ino, Loop.ino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]
2024-11-19 Bugfix with update sound
    [Sound.ino]
2024-11-28 updating to hardware version 2.0
    [MicroUSB.stl, body_housing.stl]
2024-11-28 Updating BOM an manual for FreeVario V2
    [Bill_of_Material.xlsx]
2024-12-05 improving device detection
2025-05-20 Bug fix wind direction when connected to Larus directly
    [FreeVarioGauge.ino, SerialScan.ino, VarioSound_V1.x.ino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]
2025-06-29 bugfix: set STF or vario dosen't work
    [FreeVarioGauge.ino, SerialScan.ino, VarioSound_V1.x.ino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]
2025-07-06 bugfix: switching between STF, vario and automatic mode
    [SerialScan.ino, Setup.ino]
